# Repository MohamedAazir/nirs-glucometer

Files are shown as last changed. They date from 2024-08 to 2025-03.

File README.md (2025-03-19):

# Aprick by Meditrones
<p align="center">
Aprick
</p>
In our 2nd semester, for the module BM 1190 Engineering Design Project we came up  with an idea for building a Non - Invasive Bloodglucometer using NIR. So, this repository contains the whole work related to our project. The content includes, 

- [Problem Statement](#problem-statement)
- [Our Solution](#our-solution)
- [Technical Architecture](#technical-architecture)
- [PCB Design](#pcb-design)
- [Enclosure Design](#enclosure-design)
- [Problems Encountered and Solutions](#problems-encountered-and-solutions)

## Problem Statement
Diabetes is a chronic metabolic disorder that occurs when the body either does not produce enough insulin or cannot effectively use the insulin it produces. Without proper insulin function, glucose builds up in the bloodstream, leading to high blood sugar levels (hyperglycemia), which can cause serious health complications.
Diabetes management requires frequent blood glucose monitoring, typically done using **finger-prick glucometers**. However, this traditional method presents several challenges:  
- **Pain & Discomfort**: Repeated pricking can be painful, discouraging frequent monitoring.  
- **Risk of Infection**: Regular use of lancets increases the chance of **skin infections** and irritation.  
- **Disease Transmission**: Sharing glucometers without proper sanitization can spread **bloodborne diseases** such as Hepatitis and STDs.  
- **Needle Phobia**: Individuals with a fear of needles often avoid testing, leading to **poor glucose regulation**.  

These challenges highlight the **need for a non-invasive, pain-free, and user-friendly alternative** that ensures continuous glucose monitoring without compromising accuracy.  

## Our Solution  
As a solution for this issue We proposed a solution of developing a **NIR Based Non-Invasive Glucometer** that allows diabetes patients to check their glucose levels **without drawing blood**.  

### Key Features of the Device
- **Non Invasive**: No need of pricking again. The device functionality is totally non invasive and painless.
- **Real-time monitoring**: The device provides real-time values of the blood glucose levels.
- **User friendly**: Simple finger placement mechanism for hassle-free use. OLED display for clear and easy-to-read results.
- **Portable**: Compact, lightweight design for easy carrying.

## Technical Architecture
The technical perspective of our device comprises of **four main parts**:

### 1. Signal Transmission & Reception  
<p align="center">
  Description

</p>
The process begins when an near-infrared (NIR) beam is emitted by an IR LED with a wavelength of 940 nm. As the infrared light passes through the skin and tissue, it interacts with the biological components in the finger, primarily the blood. Specifically, the near-infrared light is absorbed by glucose molecules present in the blood. The absorption of light by these molecules causes a reduction in the intensity of the transmitted light. The remaining light is then detected by a photodetector, which is the CJ-MCU OPTO 101 module, which is sensitive to the intensity of the incoming light. This photodetector generates a corresponding voltage signal based on the amount of light it receives, which varies depending on the concentration of glucose in the blood. This voltage signal is then sent to the processing unit for further analysis. 

### 2️. Signal Processing & Analysis  

<p align="center">
  Description

</p>
The received signal first passes through a passive high-pass filter. The purpose of this filter is to eliminate any DC offset present in the signal, ensuring that only the variations in the signal, such as the fluctuations caused by glucose absorption, remain. This step is crucial because DC offsets can distort the signal, leading to inaccurate measurements.

Next, the signal is passed through a first-order active low-pass filter. This filter is designed to remove unwanted high-frequency noise that may be present in the signal. High-frequency noise, which can originate from various sources such as electrical interference or environmental factors, can obscure the desired signal and affect the accuracy of the measurement. The active filter helps to preserve the low-frequency components of the signal, which are more relevant for detecting glucose levels, while attenuating the higher-frequency noise.

After the signal has been filtered, it is then sent to an amplifier. The amplifier increases the amplitude of the signal, making it more suitable for further processing or analysis. This amplification ensures that the signal is strong enough to be accurately interpreted by subsequent stages of the system.

### 3️. Glucose Level Calculation & Display  
Finally, after the signal has been amplified and processed, it is sent to a pre-trained Linear Regression model. This model has been trained on a dataset that correlates voltage signals with known blood glucose levels, enabling it to make predictions based on the processed signal. The model applies the learned relationship between the voltage variations and glucose concentrations, using the input voltage signal to calculate the blood glucose level in real-time. Once the model processes the signal, the estimated blood glucose level is displayed on an OLED screen in milligrams per deciliter (mg/dL), which is the standard unit for measuring blood sugar levels.

### 4️. Power Supply System  
The device is powered by a 3.7V 500mAh LiPo battery, chosen for its lightweight and high energy density, ideal for portable use. A booster module increases the battery voltage to 12V. This 12V is then regulated down to 5V using a voltage regulator, which powers the microcontroller, amplifier, filters, and OLED display. The voltage regulation ensures stable operation and protects sensitive components from voltage fluctuations, allowing the device to run efficiently while optimizing battery life.  

## Firmware

The firmware for the microcontroller is written in C++ using the PlatformIO IDE. It handles the calculation of blood glucose values by applying the pre-trained Linear Regression model to the processed voltage signal. The firmware also manages displaying the glucose levels on the OLED screen in real-time and updates the display with the current value in mg/dL. Additionally, it indicates the status of the device, at which stage the process currently lies on.

<p align="center">
   Description
</p>

## PCB Design

To accomplish the tasks in our project, we designed two PCBs: the emitter LED PCB and the main PCB. The emitter PCB is a single-layer design, optimized for simplicity and functionality. The main PCB, on the other hand, is a more complex two-layer design, allowing for better routing and integration of components. Both PCBs were designed using Altium, a professional PCB design software, to ensure precision and reliability in the layout. Once the design was complete, the PCBs were printed and manufactured by JLCPCB, a trusted provider of high-quality PCB fabrication services.

<p align="center">
  Description

</p>

<p align="center">
  Description

</p>

## Enclosure Design
The enclosure of our device is inspired by the general structure of a pulse oximeter, ensuring a compact, ergonomic, and user-friendly design for comfortable handheld use. It consists of four main parts: the top lid, top compartment, bottom compartment, and bottom lid. These sections are carefully designed to securely house the internal components while providing ease of access for assembly and maintenance.

For increased accuracy, enhanced comfort and stability, we have used black TPU (Thermoplastic Polyurethane) material for the padding where the user inserts their finger. TPU is chosen for its flexibility, durability, and soft texture, ensuring a snug fit while minimizing discomfort during measurements. The rest of the enclosure is 3D-printed using PLA.
<p align="center">
  Description

</p>
<p align="center">
  Description

</p>

## Problems Encountered and Solutions

- **Noise in Circuit**: Resolved by utilizing active filters.
- **IR Receiver Issues**: Switched to the CJ-MCU OPTO 101 module hoping for better performance. But it didn't provide accurate results as expected.
- **Ethical Issues**: encountered an ethical issue of getting a large enough dataset to train the linear regression model.

## Our Team

- [@MohamedAazir](https://github.com/MohamedAazir)
- [@msboralugoda](https://github.com/msboralugoda)
- [@Banu-Liyanage](https://github.com/Banu-Liyanage)
- [@Madusanka20](https://github.com/Madusanka20)

</p>
<p align="center">
  Description

</p>

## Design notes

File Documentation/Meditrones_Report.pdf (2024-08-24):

# University of Moratuwa

## Faculty of Engineering

## Department of Electronic and Telecommunication Engineering


# NIR Based Non-Invasive Glucometer

## BM 1190: Engineering Design Project

## Group Members

Index Number Name

220005R | Aazir M.M.M.
220074B | Boralugoda M.S.
220362G | Liyanage D.L.B.B.
220374U | Madusanka S.P.S.

## Abstract

### Non invasive glucometer provides a prospective approach for patients

### with diabetes with the advantages of no pain and enabling continuous

### monitoring. A near infrared LED and photo detector is used to measure

### the blood concentration. The blood glucose level is calculated based on

### the scattering and absorption of infrared light through blood and then

### displayed on OLED.With our device we hope the patients can get an

### indication about the glucose level and take necessary actions. We believe

### the user friendliness of the device will meet the user needs of the target

### market as well as ensure the technical feasibility of the device to expected

levels of the market.

# Contents

1. Problem Description
(a) 1.1 Arriving at the Problem | 3
(b) 1.2 Arriving at a Solution | 3
(c) 1.3 Motivation | 3
(d) 1.4 Justification | 3
2. Feasibility
(a) 2.1 Technical Feasibility | 4
i. 2.1.1 Hardware Feasibility | 4
ii. 2.1.2 Software Feasibility | 5
(b) 2.2 Economic Feasibility | 5
3. Usage | 5
4. Product Architecture | 5
5. PCB Design | 7
6. Enclosure Design | 8
7. Final Product and User Guidance | 9
8. Problems Encountered and Solutions | 9
9. Marketing, Sales, and After-Sale Service Analysis | 10
10. Task Allocation | 10
11. Project Budget | 11

## Problem Description

### 1.1 Arriving at the Problem

There are several reasons not to use a traditional finger prick glucometer:

- Some diabetes patients require regular testing of blood glucose levels, and using the finger prick can be painful. This pain might create reluctance in them to take regular tests, which can be risky for some patients.
- Due to the needle used in finger pricks, it can cause skin infections and irritations with regular use of the same needle.
- If the same glucometer is used by several patients, there is a high risk of spreading blood-based diseases such as STD, Hepatitis, Malaria, etc.
- A certain group of people who fear needles and who are hemophobic might face several difficulties in using the traditional glucometer.

### 1.2 Arriving at a Solution

Non invasive glucometer provides a prospective approach for patients with diabetes with the advantages of no pain and enabling continuous monitoring. A near infrared LED and photo-detector is used to measure the blood concentration. The blood glucose level is calculated based on the scattering and absorption of infrared light through blood. 940nm was chosen as suitable wavelength as it optimizes the absorption by glucose molecules.

### 1.3 Motivation

The proposed device is capable to overcome the shortcomings in the traditional invasive methods to measure blood glucose levels and make it comfortable for the user.The user friendliness of the device makes it suitable for usage by any person and get an indication about their glucose levels anywhere at anytime.This device also leads the pathway for CGM(Continuous Glucose Monitoring) which can be vital for early detection of diabetes.

### 1.4 Justification

As per the survey conducted by our team Meditrones that included several groups of people who were suffering from diabetes or had close proximity to a diabetes patient revealed that the majority of them have access to a diabetes patient.

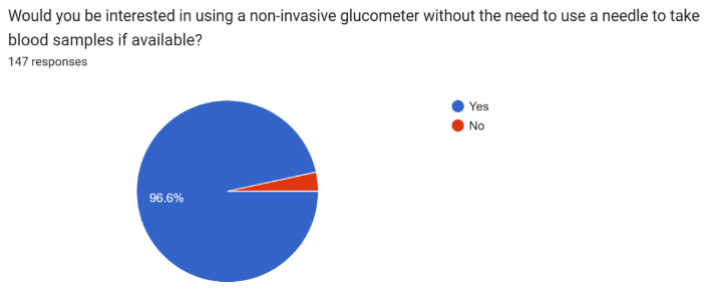
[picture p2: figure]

Figure 1: Survey Results

We believe that a non-invasive glucometer would be an ideal replacement for the finger prick glucometer and can be more user friendly for the patients but it requires to maintain a precise accuracy in the readings as well which could be a challenge in our project however with the deployment of proper technological methods we are eager to make it a reality so that we can make blood glucose monitoring more efficient and safe.

## 2. Feasibility

### 2.1 Technical Feasibility

All our resources were obtained easily from the local market thus it is technically feasible.Filter circuits and amplification processes were done from circuits built using passive and active elements. PCB was designed by us and the components were soldered by us to the PCB, the enclosure was also designed by us and got it printed using PLA+ white and black material using 3D printing.

### 2.1.1 Hardware Feasibility

All the required hardware components were available in the local market and we were able to implement the expected circuit from them. Following hardware components were mainly used in our project:

- Atmega 328P-AU
- SMD Resistors
- Ceramic and mylar Capacitors

- JST connectors and step up booster
- CJ-MCU OPTO 101 light reciever module
- Main PCB to connect other components

### 2.1.2 Software Feasibility

Software requirements for our micro controller are C++.The software utilizes algorithms to process sensor data, calibrate readings, and ensure accurate glucose level estimation without the need for invasive procedures.Overall, the software is feasible with a focus on accurate data processing, user-friendly interface, and reliable performance integration with the non-invasive sensor.

### 2.2 Economic Feasibility

The device aims to address the significant market need for non-invasive glucose monitoring. Potential benefits include reduced long-term healthcare costs due to improved diabetes management and patient compliance in comparison to the invasive methods that requires constant replacement of pricks which could be costly.The target pricing should be competitive yet reflective of the value provided by non-invasive monitoring, considering both production costs and market expectations.
Overall, the economic feasibility indicates that with strategic cost management and a clear market advantage, the non-invasive glucometer is a viable investment.

## 3. Usage

This device targets individuals that requires to get an indication about the blood glucose levels and get necessary actions for further medications. We expect this device to be used in households only to get a substantial idea about the current glucose level and to make sure early identification is done for patients with high risk without the need of invasive methods.

## 4. Product Architecture

The product architecture consists of the following sub-systems:

i. Signal Transmission and Receiving

We use a Receiver Module(CJ-MCU OPTO 101) to receive the IR beam emitted by an IR LED of wavelength 940nm implemented on the PCB and the output voltage of the module is fed into the next circuit for further analysis.

ii. Signal Analysis

The received voltage signal is sent through a low pass filter to cut off the power line interference and then through a high pass filter to make it a band pass signal within the centre frequency of the glucose resonant frequency, all the filter circuits are active filters making it more suitable for signals with high noise then the output of this circuit combination is fed into the MCU.

iii. Output

After proper analysis of the received signal to the MCU it compares the voltage value with the pre calibrated values and the corresponding calculated glucose value will be displayed on the OLED screen.

iv. Power supply

Power to the circuit is obtained using a 3.7V 500mAh Lipo battery and it is fed into a up convertor booster of 1.5A to obtain an output voltage of 12V which is then regulated to 5V using a voltage regulator and distributed along the PCB for the relevant connections.

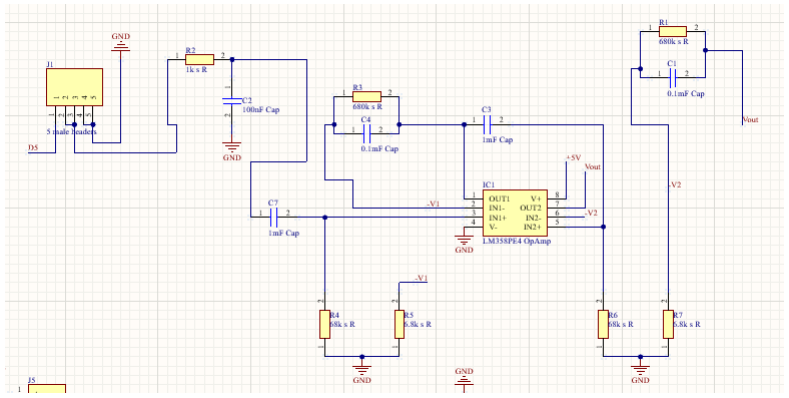
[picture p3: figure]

Figure 2: Filtering and Amplifying Circuit

## 5. PCB Design

The PCB Design of our device is shown below where we had one main PCB and another PCB for the transmitter:

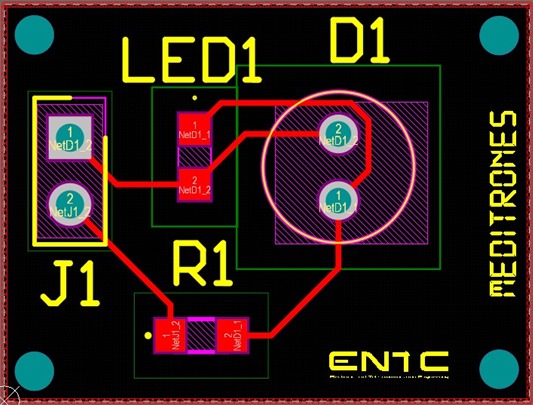
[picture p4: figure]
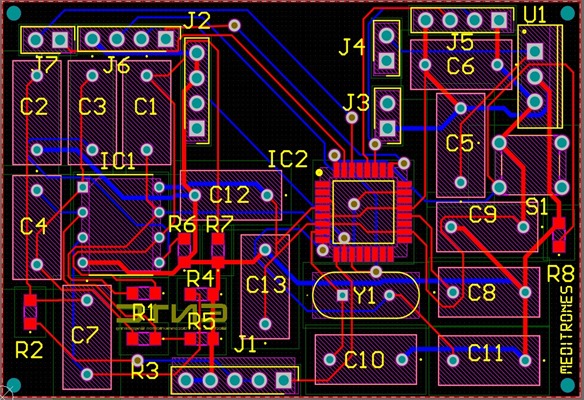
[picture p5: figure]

Figure 3: Main PCB | Figure 4: PCB for transmitter

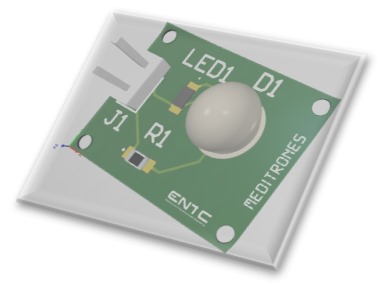
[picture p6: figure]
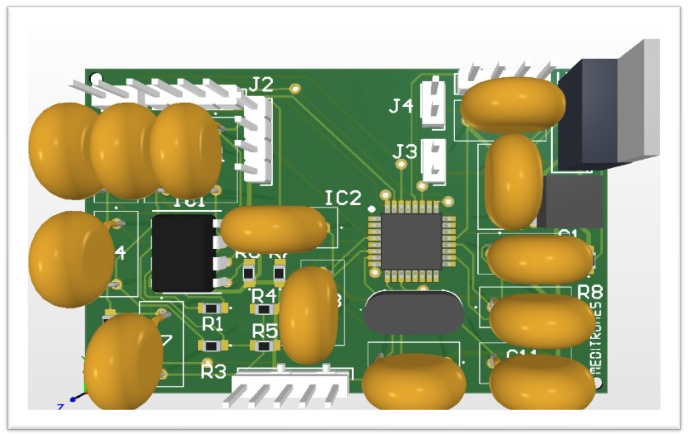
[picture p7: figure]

Figure 5: 3D view of Main PCB | Figure 6: 3D view of Transmitter PCB

## 6. Enclosure Design

The Enclosure was designed using solidworks and the sketches are shown below, we used PLA+ material to print our enclosure and Black TPU for the padding:

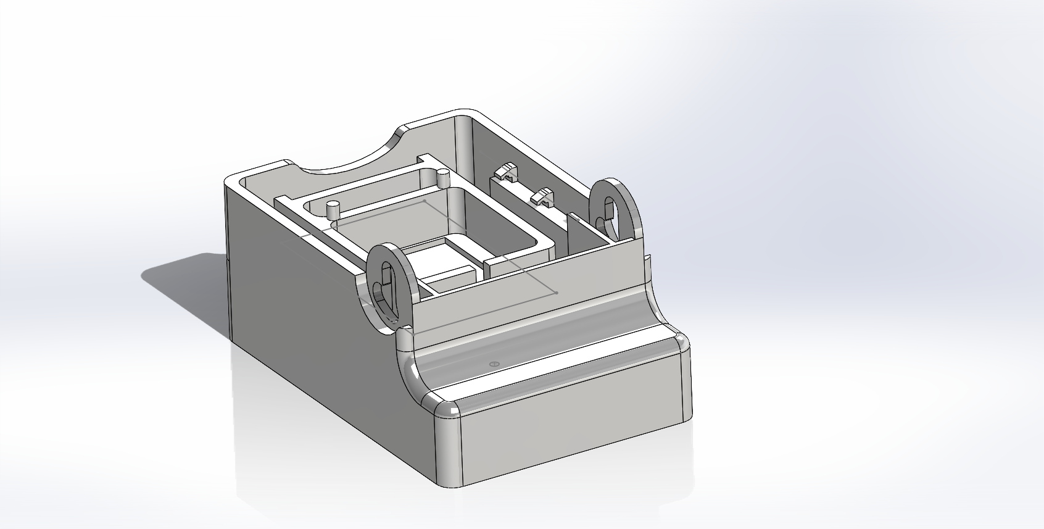
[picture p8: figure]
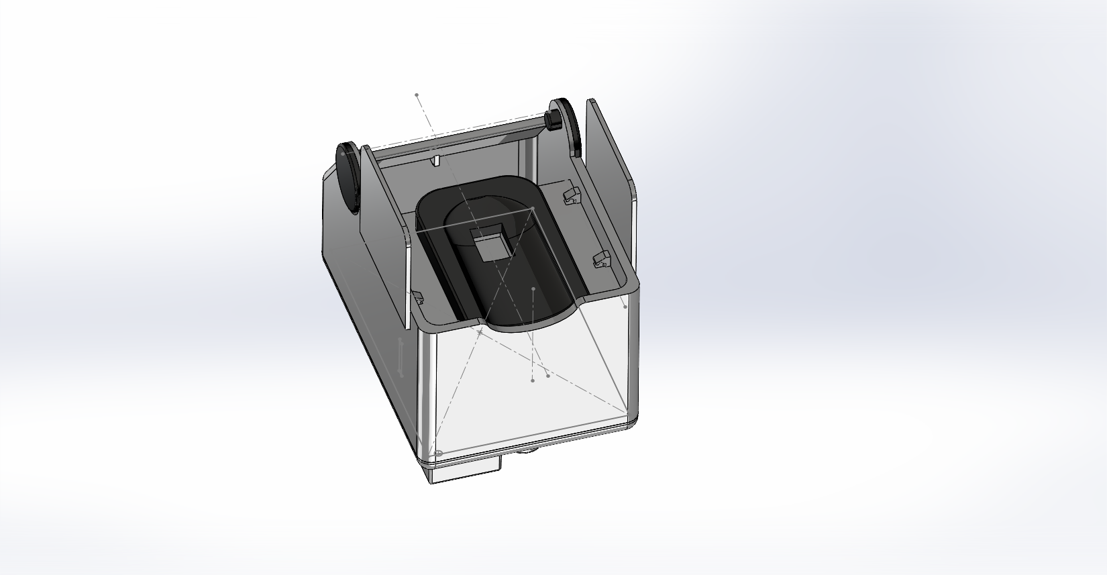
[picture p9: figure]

Figure 7: Bottom Compartment

Figure 8: With finger padding

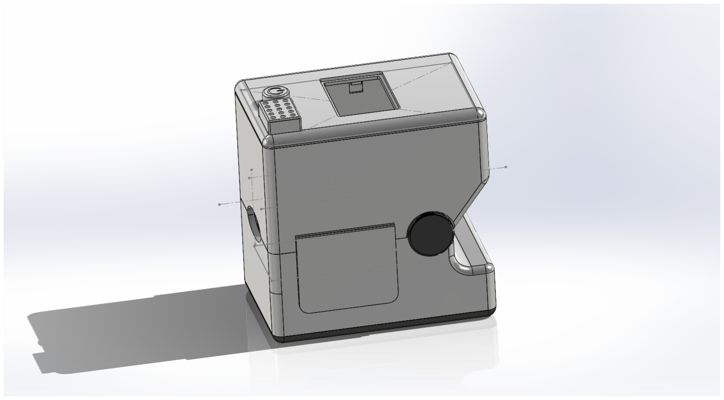
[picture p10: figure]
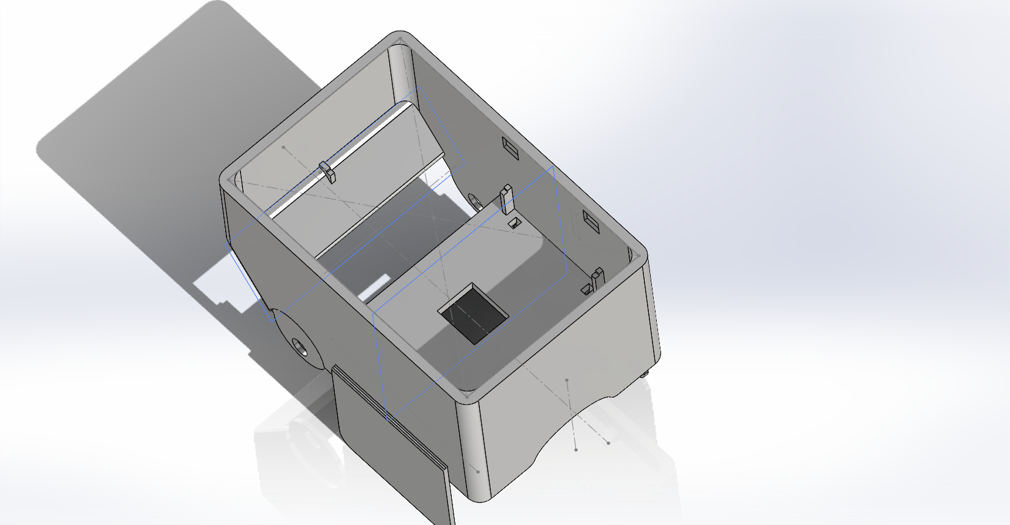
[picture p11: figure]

Figure 9: Combined Compartments | Figure 10: Top Compartment

## 7. Final Product and User Guidance

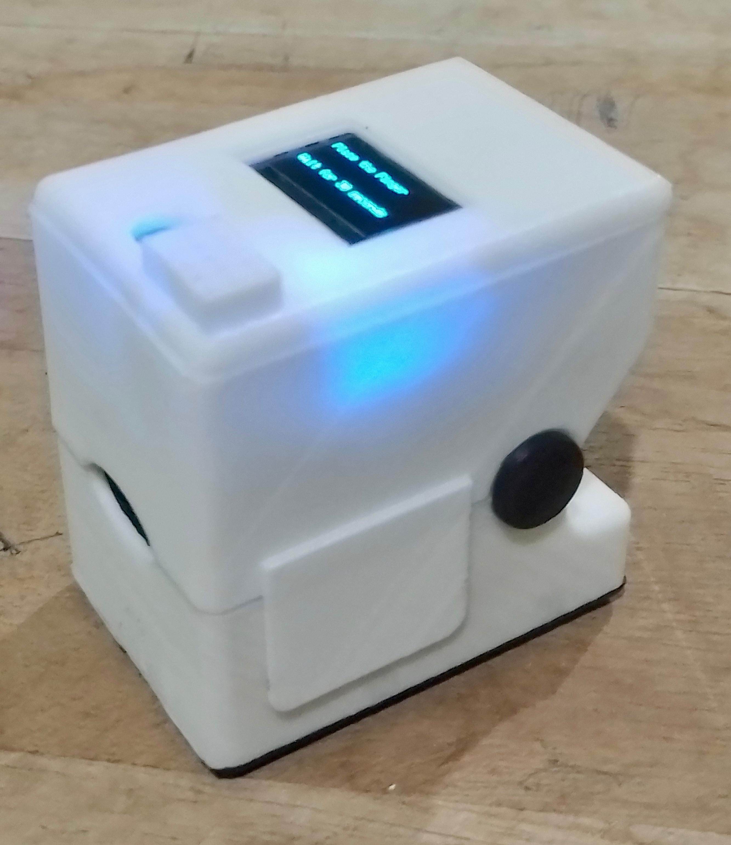
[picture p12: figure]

Figure 11: Final Assembled Device

Press the power button to turn on the device. Open the clamp and place your finger inside with the nail facing upwards. Ensure your finger is fully inserted, then release the clamp. Remain still while the device is measuring to get an accurate reading. The device will automatically start measuring your blood glucose level. Read the Results after 30 seconds, the results will display on the screen.The glucometer will automatically turn off after a few seconds of inactivity.

## 8. Problems Encountered and Solutions

1. Finalizing the circuit was a challenge at first due to extreme noise and filter deformations,as a solution we decided to utilize active filters and we got better results afterwards, furthermore to reduce the cost we used a dual Op-amp for the filters.
2. We were not able to obtain a reasonable output from the traditional IR receiver LED thus we decided to use a light receiving module (CJ MCU-OPTO 101) which gave us expected results.
3. Due to a technical faulty we were not able to program the atmega 328p-au chip but we used a TQFP-32 clamp shell and successfully uploaded the code afterwards.

## 9. Marketing, Sales, and After-Sale Service Analysis

Marketing Strategy

Our primary focus will be to educate the public on the non-invasive glucometer’s convenience and safety for household use. The device is designed to provide an indication of blood glucose levels, helping users monitor their health at home. However, it is essential to consult a healthcare professional for diagnosis and treatment decisions. Marketing efforts will include collaborations with local pharmacies, clinics, and online campaigns targeting individuals and families managing diabetes.

Sales Approach

The glucometer will be available for purchase at local pharmacies and through an online store, making it easily accessible to households across Sri Lanka. We will also work with healthcare providers to promote the device as a supplementary tool for at-home monitoring.

After-Sale Service

We are committed to supporting our customers with after-sale services that include guidance on proper use, customer support , and routine updates. It’s important to note that while the glucometer is useful for regular monitoring, it should not replace professional medical advice. Always consult a doctor for accurate diagnosis and treatment.

## 10. Task Allocation

- Research: Aazir, Manuri, Banuka
- Circuit Development: Aazir, Banuka, Sahan
- PCB Design: Sahan
- Enclosure Design: Aazir, Manuri
- Circuit Implementation: Banuka, Sahan
- Code: Aazir, Banuka
- Documentation: Manuri, Banuka

## 11. Project Budget

Component | Unit Price | Quantity | Price(Rs.)
Passive Elements | | | 100
Dual Op-Amp | 30 | 1 | 30
OLED Display | 450 | 1 | 450
PCB | | | 350
3D Printing | | | 2500
Receiver Module (CJ MCU-OPTO 101) | 2000 | 1 | 2000
JST Connectors | 20 | 3 | 60
Lipo Battery | 200 | 1 | 200
Booster Module | 150 | 1 | 150
5V Regulator | 50 | 1 | 50
Atmega 328P-AU Chip | 1500 | 1 | 1500
Push Button | 10 | 1 | 10
Total | | | Rs.7400

Table 1: Project Budget

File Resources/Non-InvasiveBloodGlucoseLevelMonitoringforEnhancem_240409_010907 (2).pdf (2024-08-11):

Non-Invasive Blood Glucose Level Monitoring for Enhancement using ML (https://www.researchgate.net/publication/360289594_Non-Invasive_Blood_Glucose_Level_Monitoring_for_Enhancement_using_ML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)

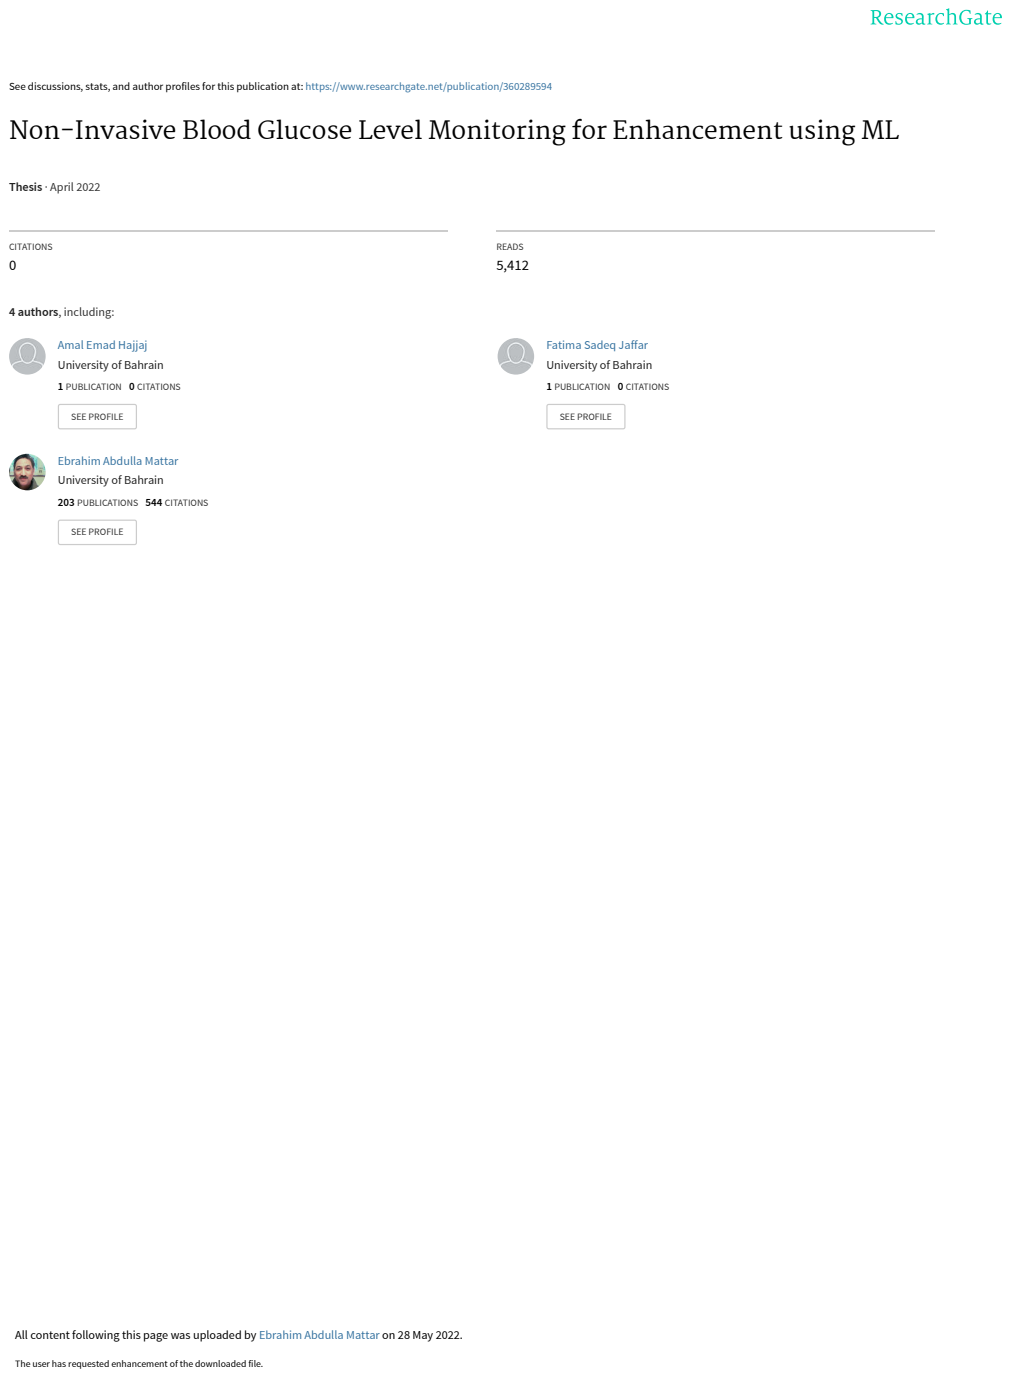
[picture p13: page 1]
Thesis · April 2022; CITATIONS 0; READS 5,412; 4 authors, including:; 1 PUBLICATION 0 CITATIONS; SEE PROFILE; 203 PUBLICATIONS 544 CITATIONS

See discussions, stats, and author profiles for this publication at: https://www.researchgate.net/publication/360289594

Amal Emad Hajjaj (https://www.researchgate.net/profile/Amal-Hajjaj-3?el=1_x_5&_esc=publicationCoverPdf)
University of Bahrain (https://www.researchgate.net/institution/University_of_Bahrain?el=1_x_6&_esc=publicationCoverPdf)

Fatima Sadeq Jaffar (https://www.researchgate.net/profile/Fatima-Jaffar-3?el=1_x_5&_esc=publicationCoverPdf)

Ebrahim Abdulla Mattar (https://www.researchgate.net/profile/Ebrahim-Mattar?el=1_x_5&_esc=publicationCoverPdf)

All content following this page was uploaded by Ebrahim Abdulla Mattar (https://www.researchgate.net/profile/Ebrahim-Mattar?el=1_x_10&_esc=publicationCoverPdf) on 28 May 2022.

The user has requested enhancement of the downloaded file.

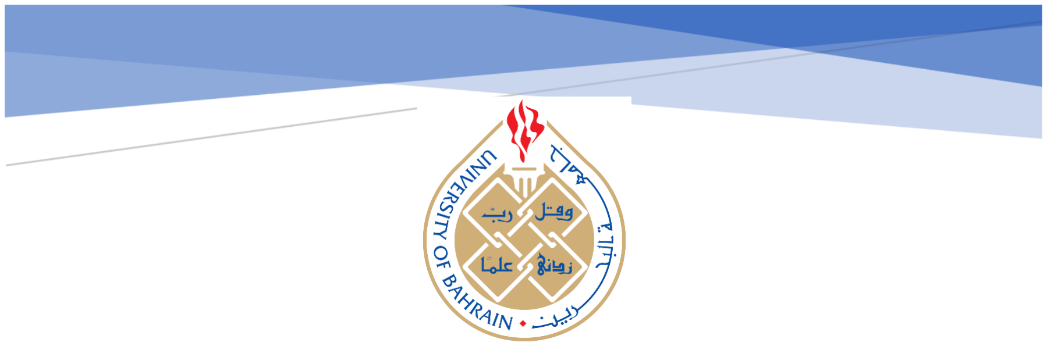
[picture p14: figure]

I

# Non-Invasive Blood Glucose

# Level Monitoring for Enhancement using ML

A Senior Design Project (EENG490) Report

Submitted in partial fulfillment of the requirements for the degree of B.Sc. in Electrical (or Electronics) Engineering

## Bahrain University

## College of Engineering

## Electrical and Electronics Engineering Department

Student Name (s) and ID:

1. Amal Emad Hajjaj 20184362
2. Fatima Sadeq Kadhem 20187159
3. Rawan Waleed Alakool 20185038

Supervisor: PROF. EBRAHIM ABDULLA MATTAR

Starting Date: 11st Feb 2022

II

# ACKNOWLEDGMENT

I would like to express our thanks and appreciation my supervisor Prof. Ebrahim

Abdullah Mattar for his continuous support and advice. Special thanks to all the helping

colleagues that helped us in understanding some of the project parts (Amnah Mohammad and

Sajjad Aljaziri), also we want to thank Mr. Mohammad (the lab technician) at the Department

stores; he has provided the parts to make our project real.

III

# STATEMENT OF AUTHENTICITY

By submitting this senior project report, we declare that:

i. We are aware and fully understand the Plagiarism Policy of the University of

Bahrain.

ii. | We have not knowingly violated any ethical codes of conduct and our work has
| taken all ethical issues into consideration.
iii. | We confirm that the research that was developed during the senior project course
| has been original work that adheres to the Plagiarism Policy of the University of
| Bahrain and has not been submitted for any other course.
iv. | We have quoted and paraphrased work done by other authors. These were
| acknowledged in the text and properly referenced in the references section.
v. We are aware and fully understand that we will be referred for investigation for
| academic misconduct, have we submitted any work which is not our own.
Students Name: | Student Signature:
1. Amal Emad | Amal
2. Fatima Sadeq | Fatima
3. Rawan Waleed | Rawan

IV

# ABSTRACT

Diabetes is a common chronic disease in mostly all countries worldwide. The most used

method to measure glucose level in blood is an invasive method which is painful, expensive

and danger in spreading infectious diseases. Over a long term, the invasive method results in

damage of finger tissues. As an alternative, the non-invasive method can be used which

facilitates frequent testing, relieves pain and discomfort caused by frequent finger pricks. A

non-invasive method of glucose level measurement is proposed in this paper. The variation in

the intensity of NIR light received from the photo detector after passing through the finger is

used to determine the glucose level of blood. The measured glucose level is displayed in LCD

display and transmitted to the android application which is created in the mobile phone to

display and store data via Bluetooth.

V

# CONTENTS

VI

VII

APPENDIX 41

VIII

# LIST OF FIGURES

IX

# LIST OF TABLES

X

# ACRONYMS

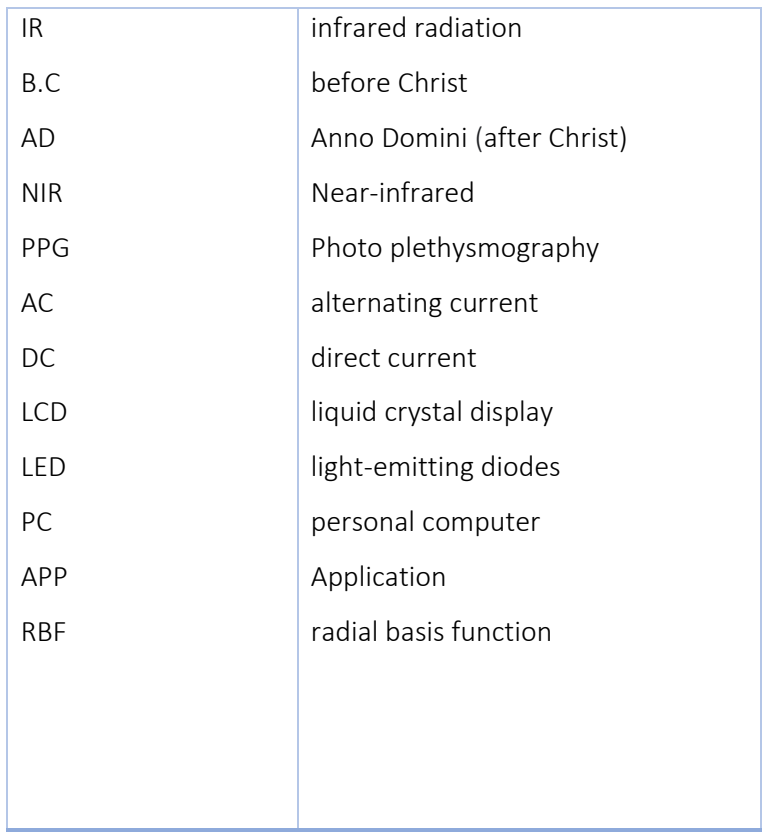
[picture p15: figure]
NIR; PPG; LCD; LED; APP; RBF; infrared radiation; before Christ; Anno Domini (after Christ); Near-infrared; Photo plethysmography; alternating current; direct current; liquid crystal display; light-emitting diodes; personal computer; Application; radial basis function

XI

# LIST OF SYMBOLS

μa

I

Mg/dl

absorption coefficient

effective optical path length

Milligrams per deciliter

# CHAPTER 1

# INTRODUCTION

Diabetes is a type a metabolic Diseases in which the blood glucose (blood sugar) level in

human body increases drastically from its normal level. The increase in sugar level is either

due to inadequate production of insulin in blood cells or can be because of improper

response of body cells to the insulin or can be because of both the reasons. diabetes can lead

to major complications like heart failure and blindness in the human body. Hence regular

monitoring of glucose level is important. There are more than 200million people with

diabetes . Diabetes is a state of a body where it is not able to produce the quantity of insulin

sufficiently required to maintain normal level of blood glucose. So, diabetic patients reg up

their blood glucose levels through proper diet as well as by injecting insulin. For the effective

treatment of diabetes, patients have to measure the level of blood glucose periodically3-5. At

present, diabetic persons are using invasive figure breaking instrument knows as glucose

meter to know the concentration of blood glucose. In pathology laboratories, glucose is

measured by piercing a patient's finger with a lancing needle. Take a small amount of blood

sample. Then a blood sample is placed on the strip and inserted in a blood glucose meter.

Development of a non-invasive glucose measurement technique would be a boom for a

diabetic patient. The major advantage of noninvasive measurement methods is the relief

from pain and comfort due to no finger puncturing. The method for glucose measurement

like IR spectroscopy is popular from years, but method with a reliable result has not been

established yet [1].

Figure 1. No for the invasive method of measuring blood sugar, [22].

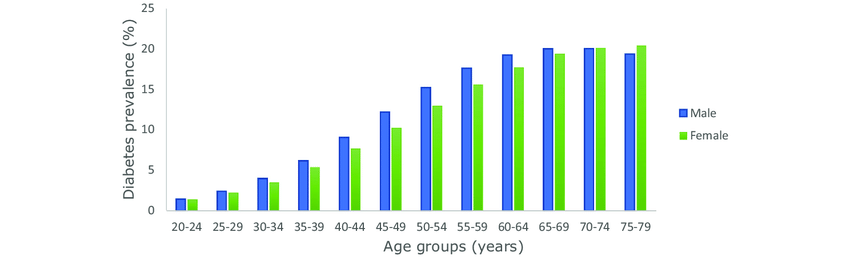
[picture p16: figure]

### 1.1 Motivation

“Health organization shows that the amount of people that got diabetes disease in 1980 is

108 million and became 422 million in 2014. Prevalence has been rising more rapidly in low-

and middle-income countries than in high-income countries. In Between 2000 and 2016,

there was a 5% increase in premature mortality from diabetes. In 2019, diabetes was the

ninth leading cause of death with an estimated 1.5 million deaths directly caused by

diabetes”. After we saw the numbers and the amount of people that suffers from needles and

injections, we wanted to help them in having an easy life without the pain of the injunctions

whenever they want to measure their blood glucose.

## 1.2 Aim of the project

The way that this project works is that we used an IR sensor with a special wavelength that

can penetrate the skin of the finger, this IR wave will go through the finger and collide with

the blood cells which cause a reflection, after the reflection of the wavelength the receiver

will receive this wave, then the Arduino will process the wave and find the glucose level of

the, what proves that the project works perfectly if the percentage error between the

invasive method and the noninvasive is a very small percentage.

Figure 2: Diabetes prevalence by age and sex in 2019, [18]

## 1.3 Constraints

The project includes many constraints that must be taken into account to ensure the

success of the project:

i. To obtain guaranteed results, the sensor must be placed on a solid and stable

surface such as a table or wood, and when placing the finger on the sensor, it must

be pressed firmly and firmly, and it must also be pressed for 10-15 seconds to

obtain a stable result.

ii. The environment of the experiment, the light and the temperature had an effect

on the results, so we tried to work under constant conditions, we also tried to

count in one place at a constant temperature and we tried to fix the finger well on

the sensor to prevent the light from entering

iii. Design, where the Arduino has a specified amount of current and voltage. One of

its Constraints is that the current works with the voltage in reverse, as when the

device takes a very large current, this leads to a significant decrease in the voltage

in the supply of the Arduino .

iv. Cost and weight, it should have an appropriate cost so that people can buy it and it

should contain lightweight components in order to be easy to carry and use .

## 1.4 Standards:

i. Arduino UNO Standards.

ii. IEEE 802.11 (Bluetooth ISM 2.4 GHz).

iii. For report departments SP standard template.

iv. 16x2 LCD Module

v. USB 3.0 and USB 2.0.

vi. TCRT5000 IR Sensor

## 1.5 Report Outline

In this report, we will talk about measuring blood sugar by a non-invasive method. In the

second chapter, we will talk about biological aspect We started by talking about diabetes and

its history, then we talked about glucose, then the layers of the human skin, then we got

acquainted with the rays that penetrate the finger and interact with glucose molecules, and

at the end of this section we learned about the method of measuring blood sugar in a non-

invasive way. In chapter3 we put our initial work, part aspect, codes and Block diagram of

proposed work. In chapter4 we put our final device, our results and error methods. In

chapter5 we talked about the discussion and in chapter6 it will be about the conclusion. At

the end of the report, we talked about Literature.

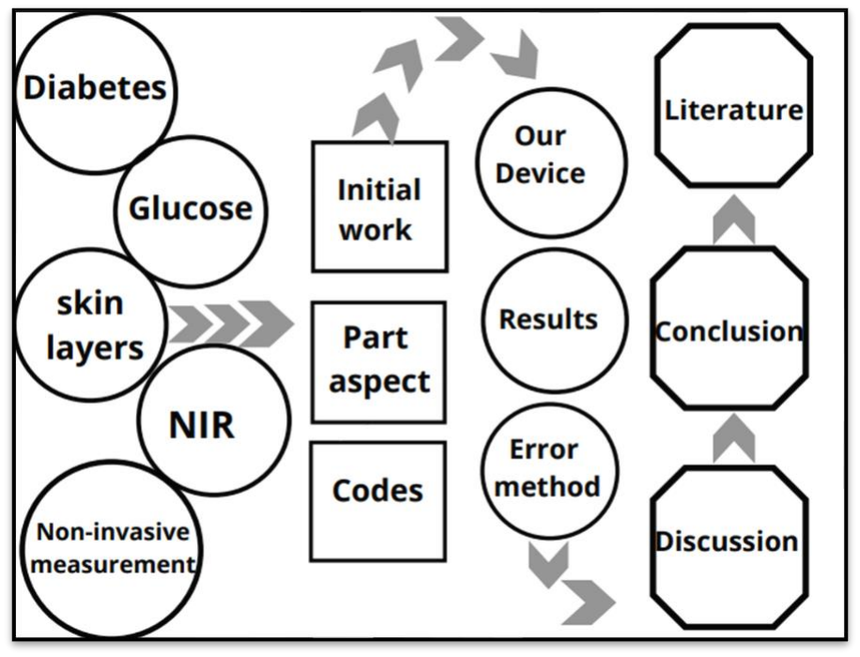
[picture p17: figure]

Figure 3: The report outline

# CHAPTER 2 BLOOD GLUCOSE BACKGROUND

## Biological Aspect

## 1.6 Diabetes history:

“Scientists and physicians have been documenting the condition now known as diabetes for

thousands of years. From the origins of its discovery to the dramatic breakthroughs in its

treatment, many brilliant minds have played a part in the fascinating history of diabetes”.

## The Literature

In this section, a literature review on measuring blood glucose using NIR spectroscopy and

measuring bilirubin using optical method has been presented. Müller et al. in 1997 used NIR

diffuse reflectance spectra method in the range of 800–1350 nm to measure glucose from

finger. The cross-validation root means square error of prediction (RMSEP) obtained is from

1.02 mmol/L (18.4 mg/dL) to 1.88 mmol/L (33.8 mg/dL). Danzer et al. in 1998 used NIR diffuse

reflectance with partial least squares (PLS) regression and analysis of radial basis function

(RBF) neural network. They used 800–1350 nm NIR light and measured glucose from the

middle finger. The RMSEP obtained is 2.0 mmol/L (36 mg/dL). Araujo-Andrade et al. in 2004

used NIR diffuse reflectance method which consisted of a light source, a fiber optical

measuring head, and an NIR spectrometer. The NIR light with a wavelength of 900–1700 nm

was used, and the measurement is carried out from the finger. In this study, the correlation

coefficient values obtained are lower than 0.744 and RMSEP values obtained are higher than

0.89 mmol/L (16 mg/dL). Xu et al. in 2005 reported an optical measurement condition

reproduction technique to deal with the difference in measuring locations and contact

pressures. Their proposed system consists of light-emitting diodes (LEDs) for lighting, fibre

probe, spectrometer, CCD camera, three-dimensional servo device, and a brocket. They used

NIR diffuse reflectance spectra in the range of 1100–1800 nm to measure glucose from palm.

The obtained RMSEP ranges from 0.8 to 1.1 mmol/L (15–20 mg/dL), and the correlation

coefficient is greater than 0.8. Guevara and González in 2010 jointed NIR (700–1000 nm) and

impedance spectroscopy (1–200 MHz). They measured glucose from the forearm and tested

technique on 10 nondiabetic individuals under controlled temperature and humidity

conditions. The RMSEP obtained was 1.2488 mmol/L (21.96 mg/dL). Srivastava et al. in 2013

proposed an optical non-invasive method to measure the blood glucose by a 940-nm infrared

light emitted as the input signal on the finger.

The output signal could be digitized, amplified, and processed in a microchip with a special

algorithm designed to detect blood glucose levels. However, the proposed method has not

been evaluated. This paper concludes that non-invasive blood glucose measurements soon

can be a good alternative to market glucometers. In 2018 three Drs made a device that

measure glucose and bilirubin, Dr. Faranak Fotouhi-Ghazvini and Fahime Sadat Zakeri. They

used for their project (microcontroller, photodiodes transmitters, resisters, capacitors, LCD,

Bluetooth module). For the microcontroller they used C++ language, they took some blood

samples and compared it with their device samples and determined an equation. Their device

was approved by the Clarkes grid analysis and the percentage was between 3% to 12%.

The second one was made with using temperature, they took 50 human samples by using

LCD, Arduino, temp sensing, and amplification, there error rate was also approved from

Clarke’s grid analysis. So, after reading more than one article we decided to use Arduino

because it has more potentials and easier in using it, we also used in our sensor two stages of

amplification stages and one low pass filter with photodiodes and transmitter, also we will use

LCD and Bluetooth module to design an application that the Arduino will send the result

through connecting the Bluetooth module to the phone application.

1.6.1 Diabetes Beginnings
“The first known mention of diabetes symptoms was in 1552 B.C., when Hesy-Ra, an Egyptian

physician, documented frequent urination as a symptom of a mysterious disease that also

caused emaciation, also around this time, ancient healers noted that ants seemed to be

attracted to the urine of people who had this disease. In 150 AD, the Greek physician Arateus

described what we now call diabetes as "the melting down of flesh and limbs into urine."

From then on, physicians began to gain a better understanding about diabetes. Centuries

later, people known as "water tasters" diagnosed diabetes by tasting the urine of people

suspected to have it. If urine tasted sweet, diabetes was diagnosed. To acknowledge this

feature, in 1675 the word "mellitus," meaning honey, was added to the name "diabetes,"

meaning siphon. It wasn't until the 1800s that scientists developed chemical tests to detect

the presence of sugar in the urine” [2].

1.6.2 The Early Treatments for the disease
“As physicians learned more about diabetes, they began to understand how it could be

managed. The first diabetes treatment involved prescribed exercise, often horseback riding,

which was thought to relieve excessive urination. In the 1700s and 1800s, physicians began to

realize that dietary changes could help manage diabetes, and they advised their patients to

do things like eat only the fat and meat of animals or consume large amounts of sugar. During

the Franco-Prussian War of the early 1870s,

the French physician Apollinaire Bouchard at noted that his diabetic patients' symptoms

improved due to war-related food rationing, and he developed individualized diets as

diabetes treatments. This led to the fad diets of the early 1900s, which included the "oat-

cure," "potato therapy," and the "starvation diet."

In 1916, Boston scientist Elliott Joslin established himself as one of the world's leading

diabetes experts by creating the textbook The Treatment of Diabetes Mellitus, which

reported that a fasting diet combined with regular exercise could significantly reduce the risk

of death in diabetes patients. Today, doctors and diabetes educators still use these principles

when teaching their patients about lifestyle changes for the management of diabetes” [2].

1.6.3 How Insulin Came About

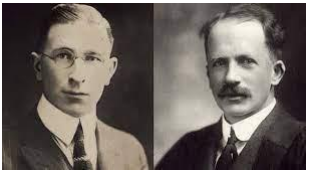
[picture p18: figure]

“Despite these advances, before the discovery of insulin, diabetes inevitably led to premature

death. The first big breakthrough that eventually led to the use of insulin to treat diabetes

was in 1889, when Oskar Makowski and Joseph von Mering, researchers at the University of

Strasbourg in France, showed that the removal of a dog's pancreas could induce diabetes. In

the early 1900s, Georg Zuelzer, a German scientist, found that injecting pancreatic extract

into patients could help control diabetes. Frederick Banting, a physician in Ontario, Canada,

first had the idea to use insulin to treat diabetes in 1920, and he and his colleagues began

trying out his theory in animal experiments. Banting and his team finally used insulin to

successfully treat a diabetic patient in 1922 and were awarded the Nobel Prize in Medicine

the following year” [2].

## 1.7 Diabetes Mellitus

Commonly known as diabetes, is a group of metabolic disorders characterized by a high blood

sugar level over a prolonged period. Symptoms often include frequent urination, increased

thirst and increased appetite, if left untreated, diabetes can cause many health complications,

Serious long-term complications include cardiovascular disease, stroke, chronic kidney

disease, foot ulcers, damage to the nerves, damage to the eyes and cognitive impairment

Figure 4: The discoverers of insulin, George Zelzer and Frederick Banting, [19].

Diabetes is due to either the pancreas not producing enough insulin, or the cells of the body

not responding properly to the insulin produced. There are three main types of diabetes

mellitus:

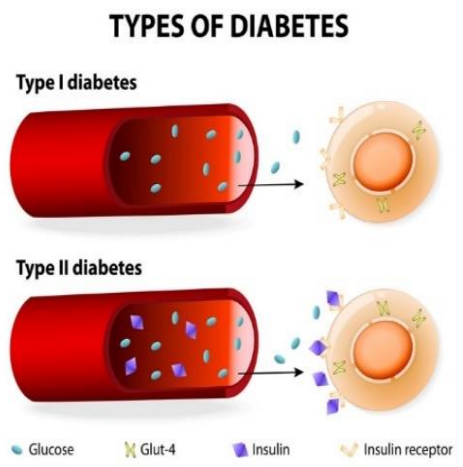
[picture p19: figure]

- Type 1 diabetes results from failure of the pancreas to produce enough insulin due to

loss of beta cells. The loss of beta cells is caused by an autoimmune response.

- Type 2 diabetes begins with insulin resistance, a condition in which cells fail to respond

to insulin properly, As the disease progresses, a lack of insulin may also develop, the

most common cause is a combination of excessive body weight and insufficient

exercise.

- Gestational diabetes, and occurs when pregnant women without a previous history of

diabetes develop high blood sugar level [4].

1.8 Glucose
Blood glucose is a sugar that the bloodstream carries to all cells in the body to supply energy.

A person needs to keep blood sugar levels within a safe range to reduce the risk of diabetes

and heart disease [5].

Figure 5: Types of diabetes mellitus [20].

What Is Glucose?
Glucose is a sugar that circulates the blood, serving as the body’s main source of energy.

When a person takes in carbohydrates, the digestive system processes them into sugar

molecules of different complexities. Complex carbohydrates, such as the lactose common in

dairy products, are harder for the body to break down. They contain different types of sugar

molecule. glucose is another product of carbohydrate breakdown. It is a simple sugar that

cells in the body can easily convert to energy. The sugar goes straight from the digestive

system into the bloodstream after an individual consumes and digests food.

However, glucose can only enter cells if enough insulin is also circulating in the bloodstream.

Insulin is a protein that makes cells ready to receive glucose. After people eat, blood sugar

concentrations increase. The pancreas releases insulin automatically to move glucose from

the blood to the cells. as more and more cells receive glucose, blood sugar levels return to

normal [5].

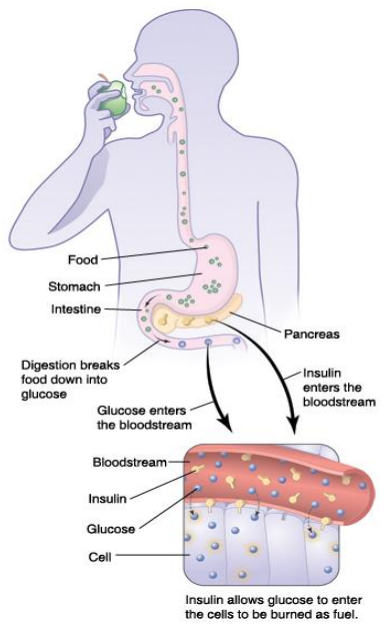
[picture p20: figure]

How The Body Makes Glucose
It mainly comes from foods rich in carbohydrates, like bread, potatoes, and fruit. As you eat,

food travels down your esophagus (https://www.webmd.com/digestive-disorders/picture-of-the-esophagus) to your stomach. (https://www.webmd.com/digestive-disorders/picture-of-the-stomach) There, acids and enzymes break it down

into tiny pieces. During that process, glucose is released. It goes into your intestines (https://www.webmd.com/digestive-disorders/picture-of-the-intestines) where it's

absorbed. From there, it passes into your bloodstream. Once in the blood, insulin helps

glucose get to your cells [6].

Figure 6: How the Body Makes Glucose, [21]

Energy and Storage
Our body is designed to keep the level of glucose in your blood constant. Beta cells in your

pancreas monitor your blood sugar level every few seconds. When your blood glucose rises

after you eat, the beta cells release insulin into your bloodstream. Insulin acts like a key,

unlocking muscle, fat, and liver cells so glucose can get inside them. Most of the cells in your

body use glucose along with amino acids (the building blocks of protein) and fats for energy.

But it's the main source of fuel for your brain. Nerve cells and chemical messengers there

need it to help them process information. Without it, your brain wouldn't be able to work

well. after your body has used the energy it needs, the leftover glucose is stored in little

bundles called glycogen in the liver and muscles. Your body can store enough to fuel you for

about a day. after you haven't eaten for a few hours, your blood glucose level drops. Your

pancreas stops churning out insulin. Alpha cells in the pancreas begin to produce a different

hormone called glucagon. It signals the liver to break down stored glycogen and turn it back

into glucose. That travels to your bloodstream to replenish your supply until you're able to eat

again. Your liver can also make its own glucose using a combination of waste products, amino

acids, and fat [6].

1.8.1 Blood Glucose Levels
blood sugar level normally rises after you eat. Then it dips a few hours later as insulin moves

glucose into your cells. Between meals, your blood sugar should be less than 100 milligrams

per deciliter (mg/dl). This is called your fasting blood sugar level.

Without enough insulin, glucose can't move into the cells. The blood glucose level stays high.

A level over 200 mg/dl 2 hours after a meal or over 125 mg/dl fasting is high blood glucose,

called hyperglycemia.

Too much glucose in your bloodstream for a long period of time can damage the vessels that

carry oxygen-rich blood to your organs. High blood sugar can increase your risk for:

a. Heart disease, heart attack, (https://www.webmd.com/heart-disease/guide/heart-disease-heart-attacks) and stroke
b. Kidney disease (https://www.webmd.com/a-to-z-guides/understanding-kidney-disease-basic-information)
c. Nerve damage (https://www.webmd.com/brain/nerve-pain-and-nerve-damage-symptoms-and-causes)
d. Eye (https://www.webmd.com/eye-health/ss/slideshow-eye-conditions-overview) disease called retinopathy [6].

## 1.9 Lifestyle tips

Lifestyle choices can often help to control blood sugar.

Eating a healthy diet with plenty of fruit and vegetables, maintaining a healthy weight, and

getting at least 150 minutes of moderate-to-intense exercise each week can help Trusted

Source. (https://www.ncbi.nlm.nih.gov/pubmed/30418471) Other tips for controlling blood sugar include:

i. eating at regular times and not skipping meals

ii. drinking water instead of juice and soda

iii. choosing fruit instead of a candy bar

iv. using portion control, so that a typical plate will be one-fourth meat, one-fourth

starchy foods, and one-half non-starchy vegetables

Any person who experiences symptoms of low or high blood sugar should see a doctor,

whether or not they have a diagnosis of diabetes [5].

## 1.10About Skin layers

The skin is the largest organ of the body, with a total area of about 20 square feet. The skin

protects us from microbes and the elements, helps regulate body temperature, and permits

the sensations of touch, heat, and cold. Skin has three layers:

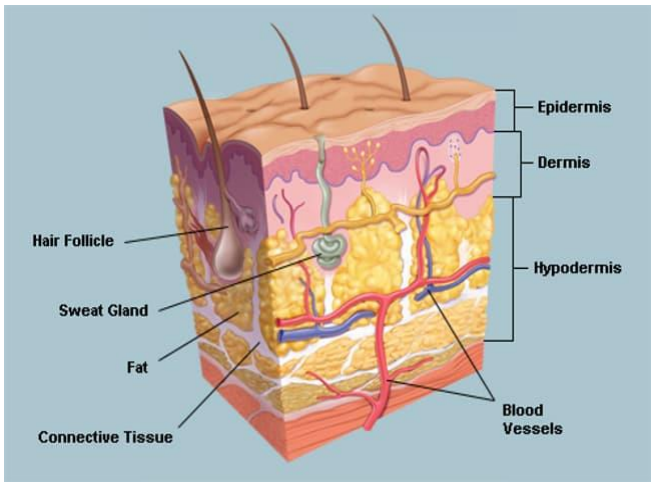
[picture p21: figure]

i. “The epidermis, the outermost layer of skin, provides a waterproof barrier and creates

our skin tone”.

ii. “The dermis, beneath the epidermis, contains tough connective tissue, hair follicles,

and sweat glands”.

iii. “The deeper subcutaneous tissue (hypodermis) is made of fat and connective tissue”.

The skin’s color is created by special cells called melanocytes, which produce the pigment

melanin. Melanocytes are in the epidermis [3].

Figure 7: The skin structure and layers, [5].

## 1.11NIR

Near-infrared spectroscopy (NIRS) is a spectroscopic method that uses the near-infrared region of the

electromagnetic spectrum (from 780 nm to 2500 nm). Typical applications include medical and

physiological diagnostics and research including blood sugar, pulse oximetry, functional neuroimaging,

there are also many applications use it.

1.11.1Range of Wavelengths

Glucose is a kind of monosaccharide with the molecular formula C6H12O6 in the form of pyranose. It has

several absorption peaks in the NIR region. where light possesses its maximum penetration depth in tissue

is referred as Near Infrared window. Glucose has light absorption peaks at wavelengths of 940 nm, 970

nm, 1197 nm, 1408nm, 1536nm, 1688nm, 1925 nm, 2100nm, 2261nm and 2326nm, but at 940 nm

wavelength the attenuation of optical signals by other constituents of the blood like water, platelets, red

Figure 8: Light skin penetration with different wavelengths (nm).

blood cells etc. is minimum, hence a desired depth of penetration can be achieved, and actual glucose

concentration can be predicted, [1].

## 1.12Non- invasive measurement:

1.12.1Measuring the level of glucose in the blood
Diagnosing systems for blood sugar system are invasive in nature. This procedure is performed by drawing

blood through puncturing the skin with a needle and applying it to a chemically active test strip. Another

procedure for diagnosing blood sugar is non-invasive method. Some of the existing non-invasive methods

are near infrared (NIR) detection, ultrasound and dielectric spectroscopy which do not need any supply

of blood for conducting the tests and calculating its result [7].

1.12.2Photo plethysmography
The skin tissue consists of three layers of which only dermis layer consists of information about blood

glucose. infra-red wavelength (780nm to 2500nm) is able to penetrate until the dermis layer, The

transmitted IR light will be absorbed by different skin tissues, different molecules in the blood like melanin,

keratin, fats, proteins, hormones etc. and the skin pigments. Variations in the volume of blood flow are

detected by the (PPG) sensors optically. It records the changes in reflected light intensity from the dermis

layer of skin. The light waveform consists of both direct Current (DC) and alternating current (AC)

components. The DC component of the PPG waveform corresponds to the optical signal is transmitted or

reflected from the tissues during changes in blood volume in this work, reflection photography It is

considered to non-invasively determine glucose levels. Here the light passes through the epidermal layer

and upon arrival, The light of the dermis is absorbed, scattered, and reflected by glucose molecules. The

intensity of light reflected from the dermis layer was examined to predict glucose levels [7].

1.12.3Principle of Blood Glucose Measurement
When a light ray interacts with human body tissues, it is attenuated by scattering as well as by absorption

by the tissues. Due to the mismatch between the refraction index of extracellular fluid and the cell

membrane, light scattering occurs in tissues. Refraction index of extracellular fluid varies with the glucose

concentration whereas the cellular membrane index is assumed to be remain relatively constant. Beer-

Lambert Law plays a major role in absorbance measurement which states that absorbance of light through any solution is in proportion with the concentration of the solution and the length path travelled by light

ray.

more glucose tissue results in less scattering, less optical path length and thus more absorption than

before tissues. Due to increased uptake in elevated glucose tissues Reflected light is less intense compared

to tissue with lower glucose content [1].

The attenuated light simply due to the absorption of analysts after they pass through tissue is governed

by the Beer–Lambert Law, which is expressed as:

## i = i0e

−iμai

Figure 9: Less glucose tissue, [1].

Figure 10: More glucose tissue, [1].

here μa is the absorption coefficient and l are the effective optical path length μa is proportional to εC

“cm−1, where ε represents the molar extinction coefficient and C is the molar concentration of the

analyte”. “μa may increase with an elevated glucose level due to its intrinsic absorption or decrease due

to a water displacement effect”.

# CHAPTER 3

# DESIGN AND IMPLEMENTATION

## 1.13 Background of experiment

To measure blood sugar in a non-invasive way, as we mentioned earlier, the NIR rays

penetrate the skin and the rays interact with the finger tissues and glucose concentration and

then are reflected, and this reflected light is an electric current and then it is converted into

an electric potential. We were looking for a lot of sensors that read the output voltage. Then

we compared the results of the effort with the concentration of blood sugar by the gaseous

method and extracted the relationship and then finished the design of the device

## 1.14Initial work

We have tried to make a sensor, circuit that contains an IR transmitter and an IR photodiode

receiver, the designed circuit consists of filtering stage and amplification stage.

We finished making the circuit and used an oscilloscope to compare the input with the output

and we noticed that there were problems, so we decided to look for another sensor.

## 1.15 Parts aspect

We choose to use these components and conclude our circuit design upon reading lots of

scientific papers and articles that were using different kind of parts, the suitable parts for our

project that fulfil the accuracy and low-cost terms, these components are:

i. Arduino

ii. IR transmitter and receiver

iii. LCD

iv. Bluetooth

v. breadboard, power supply, resistors, wires

Figure 13 Output for first sensor

Figure 12 Simulation for first circuit. Figure 11 Circuit for first sensor.

## Parts explanation:

1.15.1Arduino UNO

“Arduino Uno is a microcontroller board based on the ATmega328P (datasheet). It has 14

digital input/output pins (of which 6 can be used as PWM outputs), 6 analog inputs, a 16 MHz

quartz crystal, a USB connection, a power jack, an ICSP header and a reset button”. We will

connect all the parts with the Arduino which it makes the Arduino the main controller of the

whole device.

1.15.2 IR transmitter and receiver

We used a sensor that contains the above components which they’re 5mm 940nm IR Emitter

Transmitter LED Diode Lights, Clear Infrared DC 1.2V with 30mA and 100mW, for the receiver

it’s a 5mm Photodiode with 840nm to 1100nm spectral density and has 940nm as a peak

wavelength, after that the sensor contain an amplifier and current to voltage converter which

will convert the conducting current from the transmitter and receiver to voltage, then amplify

this voltage.

Figure 14 Arduino component

Figure 16: IR transmitter with 940nm wavelength [23] Figure 15: IR photodiode receiver with spectral range of 840nm-1100nm and a peak wavelength 940nm [24]

1.15.3LCD

An electronic device that is used to display data and the message is known as LCD 16×2. As

the name suggests, it includes 16 Columns & 2 Rows so it can display 32 characters (16×2=32)

in total & every character will be made with 5×8 (40) Pixel Dots. This part will be used in this

project to display the amount of glucose in the blood and state a comment if its [Low-

Medium- High].

1.15.4Bluetooth [HC-06]

The HC-06 is a class 2 slave Bluetooth module designed for transparent wireless serial

communication. Once it is paired to a master Bluetooth device such as PC, smart phones and

tablet, its operation becomes transparent to the user. All data received through the serial

input is immediately transmitted over the air. This module will be used at this project to

connect the smart phone to this prototype, which the devise will send a message through the

app that’s made specially for this project, the message will include the state of glucose if its

Low, Medium, or High.

Figure 17: LCD component.

Figure 18: HC_06 Bluetooth module, [25]

## 1.16Block diagram of proposed work

The proposed work is based on NIR optical technique. NIR light source of 940 nm wavelength

is chosen because it is suitable for measuring blood glucose concentration. The sensing unit

consists of NIR emitter and NIR receiver (photodetector) positioned on either side of the

measurement site (fingertip). When the NIR light is propagated through the fingertip in which

it interacts with the glucose molecule, a part of NIR light gets absorbed depending on the

glucose concentration of blood and remaining part is passed through the fingertip. The

amount of NIR light passing through the fingertip depends on the amount of blood glucose

concentration.

Figure 19:Block diagram of noninvasive glucose concentration measurement system, [9].

The transmitted signal is detected by the photodetector. The output current of the photo

detector is converted into voltage signal and then it is filtered and amplified in the sensor.

This amplified signal is fed into the Arduino. This signal is processed by using second order

regression analysis to predict the blood glucose value and the blood glucose value is displayed

on the LCD display. A mobile application (App) is created to view and store the predicted

blood glucose value after receiving it via Bluetooth. Atmel communicates to the mobile app

via Bluetooth by connecting a Bluetooth module (HC-06) to it. The flow chart of proposed

work is shown in the following diagram The circuit diagram of the designed system consists of

sensor that do filtering stage and amplification stage. The electrical current obtained from the

photo detector is converted into voltage.

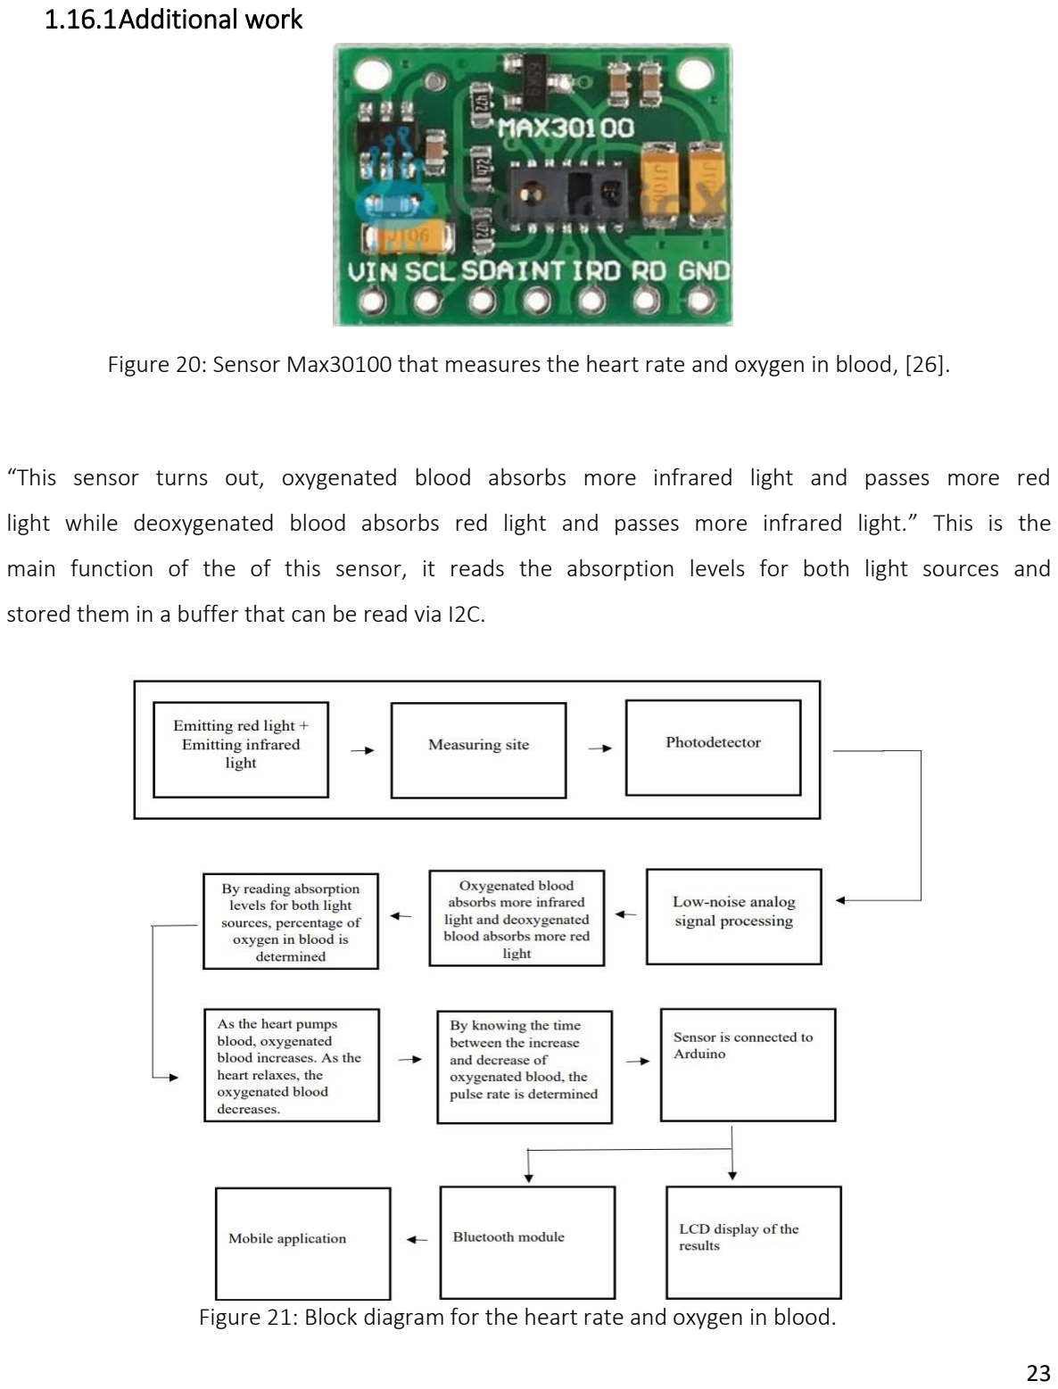
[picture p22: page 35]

1.16.1Additional work

Figure 20: Sensor Max30100 that measures the heart rate and oxygen in blood, [26].

“This sensor turns out, oxygenated blood absorbs more infrared light and passes more red

light while deoxygenated blood absorbs red light and passes more infrared light.” This is the

main function of the of this sensor, it reads the absorption levels for both light sources and

stored them in a buffer that can be read via I2C.

Figure 21: Block diagram for the heart rate and oxygen in blood.

## 1.17 Beginning of work

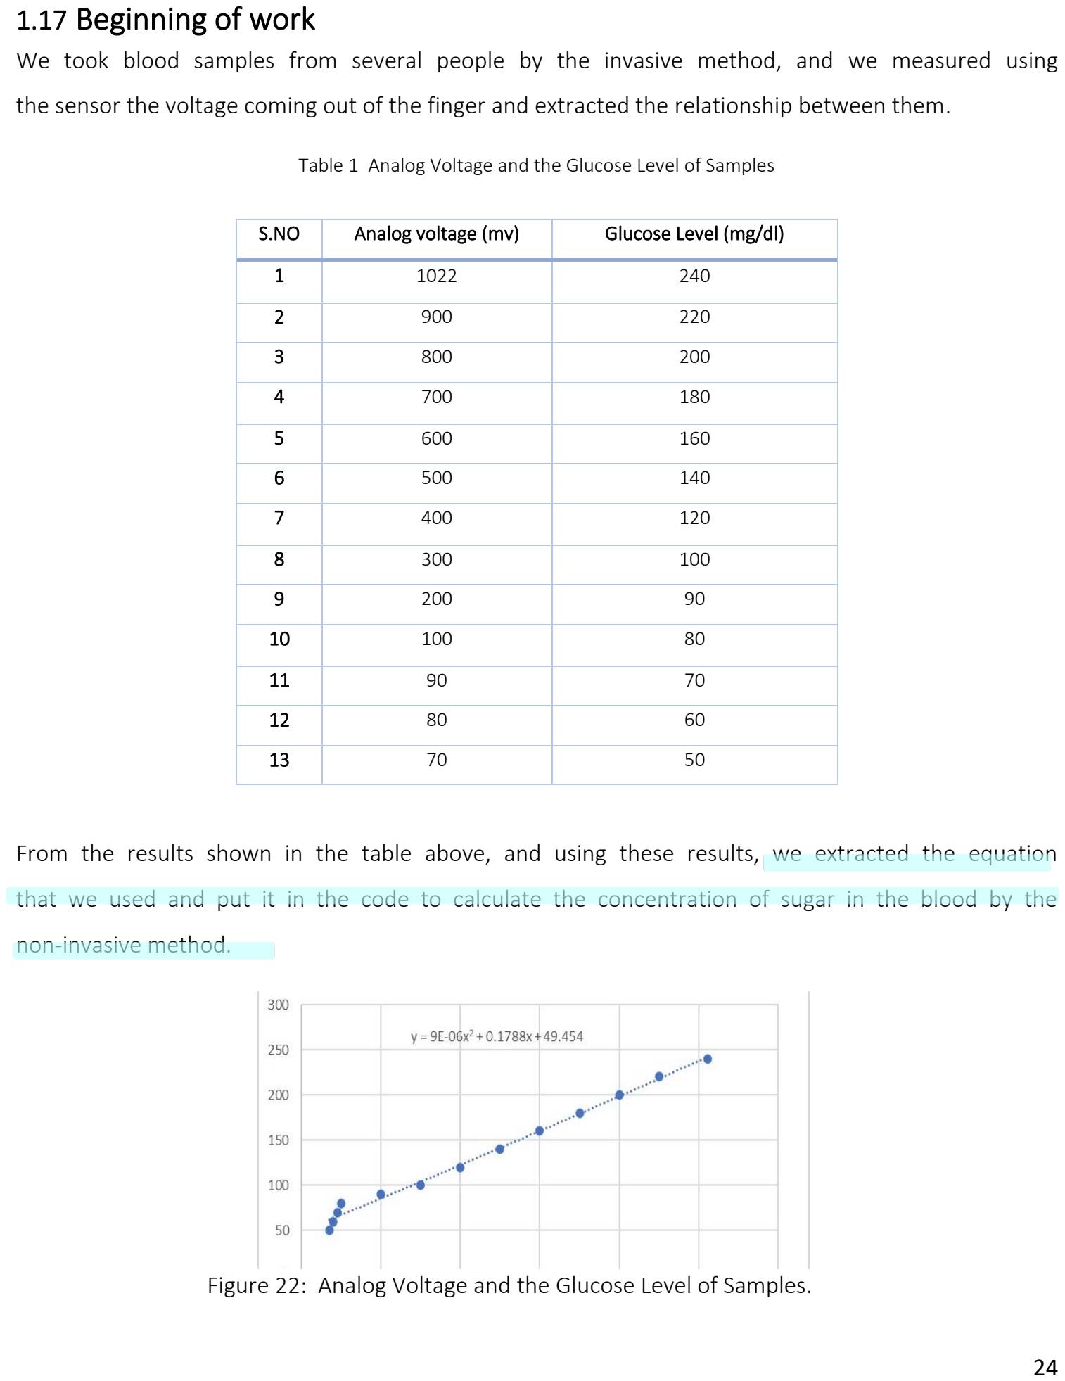
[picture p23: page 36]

We took blood samples from several people by the invasive method, and we measured using

the sensor the voltage coming out of the finger and extracted the relationship between them.

Table 1 Analog Voltage and the Glucose Level of Samples

From the results shown in the table above, and using these results, we extracted the equation

that we used and put it in the code to calculate the concentration of sugar in the blood by the

non-invasive method.

S.NO | Analog voltage (mv) | Glucose Level (mg/dl)
1 | 1022 | 240
2 | 900 | 220
3 | 800 | 200
4 | 700 | 180
5 | 600 | 160
6 | 500 | 140
7 | 400 | 120
8 | 300 | 100
9 | 200 | 90
10 | 100 | 80
11 | 90 | 70
12 | 80 | 60
13 | 70 | 50

Figure 22: Analog Voltage and the Glucose Level of Samples.

## 1.18 Flowcharts

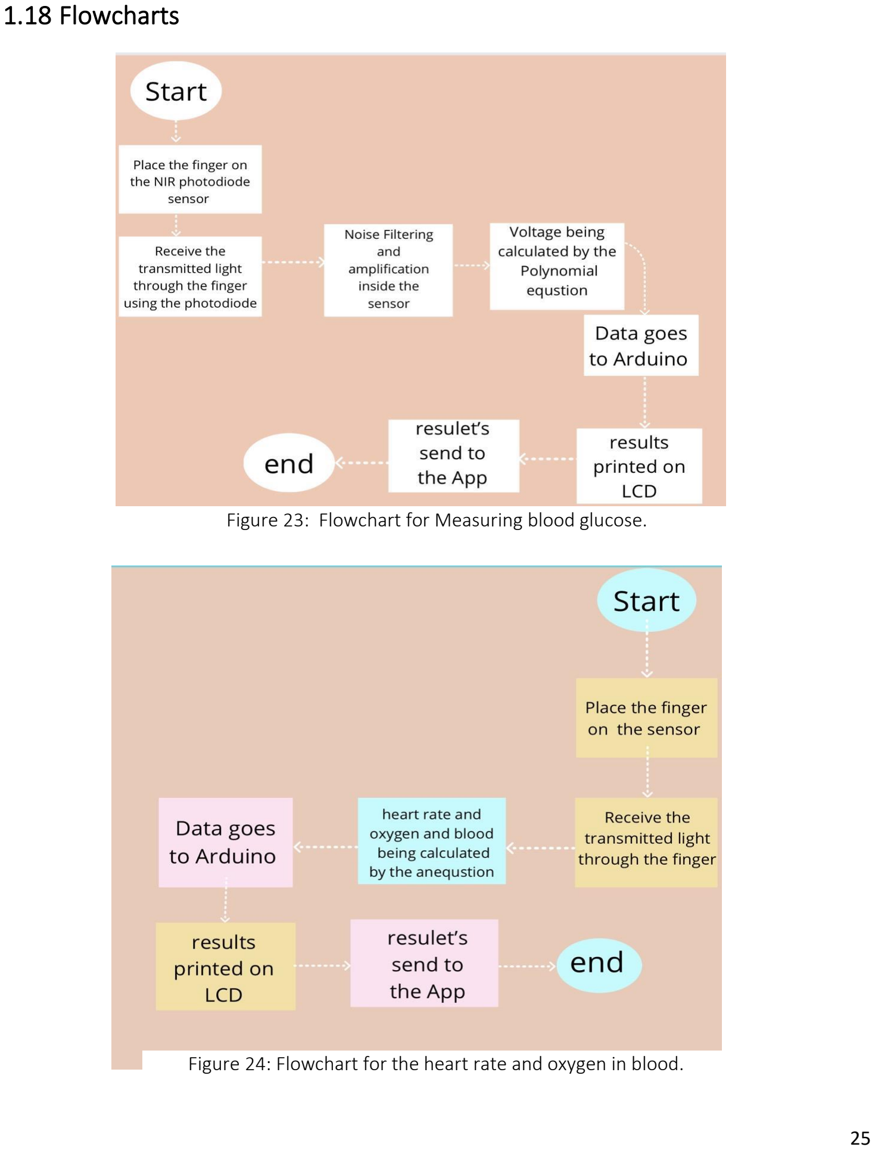
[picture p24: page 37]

Figure 23: Flowchart for Measuring blood glucose.

Figure 24: Flowchart for the heart rate and oxygen in blood.

## 1.19 Coding aspect:


We will need a C++ code (which will be installed in the Arduino microcontroller using the

Arduino software) for the following reasons:

a) To input an equation that will be used regularly.
b) We will need code for the output voltage of the photodiode for the Arduino to

recognize it as an input and process the data.

c) A code for the LCD screen for the Arduino to recognize it as an output & display result.

Figure 25: The heart rate and oxygen in blood code.

Figure 26: “Blood glucose code”.

1.19.1 Code explanation:
THE GLUCOSE CODE EXPLANATION

First, we included the library that will be used to effectively connect and program the LCD, we

also identified the Arduino pins which will be connected to the LCD, and we chose an initial

float variable to represent the voltage level that will be processed and the result of processing

the input which will represent the glucose level. Second, we identified an analog pin as an

input that will be receiving the voltage, and we also informed the program that the LCD will

have the capacity to print 16 letters for two rows. Moreover, we used the command “analog

read” to read the analog data received which is the voltage level and we set that value to a

variable. After that, we substituted the voltage level in the equation which we found earlier

by analyzing the data to get the glucose level measurement. Finally, we used “if” command

for comparison to determine the if the glucose level is Low, High, or normal and print it on the

screen along with calculated result.

THE HEART RATE AND OXYGEN IN BLOOD CODE EXPLANATION

the necessary header files for MAX30100 and 16×2 LCD. As MAX30100 uses the I2C

communication | protocol | were | included. | In | void | setup(), | we | initialized | the | Serial

Communication with a baud rate of 115200, Then test condition for MAX30100 was written.

If it is successfully initialized, then we will see “SUCCESS” on the serial terminal; otherwise, it

will display “FAILED” wait for infinite time in for loop.Now, the current through the LED was

set. By default, the current through the LED is 50mA.the current set in this code through the

IR | LED | is | 7. | 6mA.The | pulse | is | detected | from | the | sensor | by | using | the

setOnBeatDetectedCallback function, which will call the onBeatdetected. In infinite void loop

(), function pox.update() updates the sensor reading. Finally, it will print the heart rate in bpm

and SpO2 in percentage on a LCD every second.


Figure 27: The fuzzy classification system.

Figure 28: A learning fuzzy classification system.


Figure 30: An implemented fuzzy classification system.

# CHAPTER 4

# RESULTS AND DIFFICULT


## The device

This is the final form of the device, to measure sugar without pain in a non-invasive way, you

must put your finger on the sensor firmly and firmly for 15 seconds, and we have added the

device to measure the percentage of oxygen in the blood and heart rate in the human body,

so you only have to put your finger on the other sensor, the Arduino will take over Calculate

them all and then the results will be displayed on the LCD screen.

Figure 32: The final look of the device.

Figure 31: How the device works.

## 1.20 Results from our device

These are the results we got out of our device and we compered them with those we extracted from the

invasive method and we found the difference between them.

Table 2 Difference between invasive and non-invasive

S.NO | Glucose value obtained by invasive method | Glucose value obtained by non-invasive method | Difference | S.NO | Glucose value obtained by invasive method | Glucose value obtained by non-invasive method | Difference
1 | 97 | 89 | -8 | 7 | 103 | 100 | -3
2 | 119 | 99 | -20 | 8 | 150 | 130 | -20
3 | 95 | 89 | +4 | 9 | 115 | 108 | -7
4 | 100 | 99 | -1 | 10 | 90 | 108 | +18
5 | 101 | 107 | +6 | 11 | 200 | 150 | -50
6 | 99 | 113 | +14 | 12 | 79 | 89 | +10

## 1.21 The methods

The accuracy of this proposed glucose measurement device is measured using two main

analysis methods: Clarke Error Grid Analysis and Surveillance Error grid analysis.

1.21.1 Clarke Error Grid Analysis
The Clarke Error Grid shows the differences between a blood glucose predictive

measurement and a reference measurement, it also shows the clinical significance of the

differences between these values. As observed, the x-axis corresponds to the reference value

and the y-axis corresponds to the prediction. The diagonal line shows the prediction value is

the same as the reference value. This grid is split into five main zones, Zone A is defined as

clinical accuracy while zones C, D, and E are considered clinical error, [10].

ZONE A: Clinically Accurate This zone holds the values that differ from the reference values no

more than 20 percent or the values in the hypoglycemic range (<70 mg/dl). According to the

literature, values in zone A are considered clinically accurate. These values would lead to

clinically correct treatment decisions.

ZONE B: Clinically Acceptable This zone holds values that differs more than 20 percent but

would lead to benign or no treatment based on assumptions.

ZONE C: Overcorrecting This zone leads to overcorrecting acceptable BG levels.

ZONE D: Failure to Detect This zone leads to failure to detect and treat errors in BG levels. The

actual BG levels are outside of the acceptable levels while the predictions lie within the

acceptable range.

ZONE E: Erroneous treatment This zone leads to erroneous treatment because prediction

values are opposite to actual BG levels, and treatment would be opposite to what is

recommended [10].

As observed, 95% of the values are in region {A} which is considered medically acceptable

region for measurement devices, [9].

Figure 33: Result of Clarke analysis, [9].

1.21.2 Surveillance Error grid analysis
The surveillance error grid (SEG) analysis is a tool for analysis and visualization of blood

glucose monitoring (BGM) errors, it is mainly used to determine the clinical accuracy and risk

range of continuous glucose monitoring device used in intensive care unit. For each data pair

of measured and reference glucose, the experts identified the degree of risk associated with

an action taken because of a measured BG reading, compared to the action that would have

been taken if the reference BG had been known. The degree of risk for hyperglycemia

identified by the experts was coded from 0 (none) to 4 (extreme) [11]


Figure 34: Result of Surveillance Analysis, [9].

The above is our results using the Surveillance Error grid analysis, we notice that the

visualization of color-coded accuracy makes it much easier and faster to conclude that the

proposed device is acceptable for glucose level monitoring as most of the glucose readings

are in dark green zone (no risk) and few glucose readings are in light green zone (slight risk).

## 1.22 Difficulties

At first, we had a lot of difficulties in how we can design our own circuit, then things started

to be clear, the hardest part was ordering some of the components because they weren’t

available in Bahrain electrical and electronic markets, after the components arrived, we found

the coding a little bit challenging, but we’ve been able to write the perfect coding with some

helping from a famous website like GitHub.

We tried to build a whole sensor by our own, but the process was too long and ruff because

of the amplification stage and error of the amplification when it multiplied with a high gain.

So, after digging more into the subject we found a sensor that’s similar to what we wanted to

build.

The big challenge was how to obtain the glucose equation by taking the samples from the

people, the hard part was stabilizing the sensor and remove everything that affects it so we

can take true and correct readings that’s without side effects.

# CHAPTER 5

# DISCUSSION

## 1.23 Discussion

After spending time researching, designing, and implementing our glucose level monitoring

device. We succeeded in making a device for measuring blood glucose in a non-invasive way

Based on the results presented in Table 2, we compared the results of our device with the

results of the invasive method of glucose meter and we calculated the differences between

the results, the differences between the two devices were very good, but the differences

were greater when we measured high blood sugar.

i. What’s new in this project?
The new thing in our project is that we were able to measure the heart beats and

oxygen in blood beside the blood glucose.

ii. | What’s new comparing to the other articles, how do you compare your results?
| Our project differs than the articles that we read with (simple hardware and
| application, easy to use and our results are almost in the same error percentage as
| ours).
iii. | What is the project constraining, standards, limits, specifications?
| Limitations: are things that effect the sensor reading which make it not efficient and
| get higher error% they are (light, person skin thin or thick, persons weight)
| constrains: The sensor has some constrains which make it in can’t read in specific
| voltage which mean high percentage error in some points.
iv. | specifications: easy hardware, parts are available everywhere, low percentage
| error.

## 1.24 Total cost of the project

Table 3 Total cost

Device | Amount | Cost (BD)
Arduino uno | 1 | 2.500
sensors | 2 | 0 from uni
wires | 2 set of wires | 0.700
Bluetooth HC-06 | 1 | 2.500
Breadboard | 1 | 0.800
LCD | 1 | 2.000

Total cost = 8.500 BD

# CHAPTER 5

# CONCLUSION AND FUTURE WORK

To accomplish this project, we read many articles and journals to attempt to design and

implement a non-invasive Method for Glucose level monitoring. This method mainly Relies on

the NIR light. as we send the wavelength into that finger and measure the reflected amount

of the NIR which differs based on the amount of Glucose In the blood. We took samples using

the traditional invasive way and our device and found the correlation between both results

Using a mathematical equation. This equation is inserted into the Arduino’s microcontroller

and continuously used to find the glucose level in a non-invasive way. To make sure that our

results are accurate and acceptable we used two analyses to find the error percentage and it

didn’t exceed 20% which makes our device clinically acceptable for usage. This project helped

us on how to design, implement and how to bring life to what was once only an idea in our

head. we learned a lot of lessons that benefited us as students and will continue to be

valuable Information for us as engineers in the near future. As engineers, we are problems-

solvers, and we hope to bring to the medical world more designs and solutions that help

those who are in need.

# REFERENCES

[1] “NIR Based Non-Invasive Blood Glucose Measurement” Indian Journal of Science and Technology,

Vol 9(41), DOI: 10.17485/ijst/2016/v9i41/98996, November 2016 [Accessed: 17-Feb-2022]

[2] “The History of Diabetes” https://www.everydayhealth.com/diabetes/understanding/diabetes-

mellitus-through-time.aspx (https://www.everydayhealth.com/diabetes/understanding/diabetes-mellitus-through-time.aspx) [Accessed: 12-Feb-2022]

[3] “Picture of the Skin” https://www.webmd.com/skin-problems-and-treatments/picture-of-the-skin
[4] “Diabetes” https://en.wikipedia.org/wiki/Diabetes [Accessed: 22-Feb-2022]
[5] “What should my blood glucose level be?”

https://www.medicalnewstoday.com/articles/249413#what-is-a-healthy-blood-sugar-level [Accessed: 1-

March-2022]

[6] “What Is Glucose” https://www.webmd.com/diabetes/glucose-diabetes [Accessed:3-March-2022]
[7] “Non-Invasive Blood Glucose Monitoring Using Near Infrared Spectroscopy”

https://www.researchgate.net/publication/352244798_non_invasive_glucose_monitoring_2018

[Accessed: 2-Feb-2022]

[8] “Noninvasive Optical Diagnostic Techniques for Mobile Blood Glucose and Bilirubin Monitoring”

Bahareh Javid, Faranak Fotouhi- Ghazvini, Fahime Sadat Zakeri Department of Computer Engineering

and Information Technology, University of Qom, Qom, Iran [Accessed: 7-March-2022]

[9] “BLOOD GLUCOSE LEVEL MONITORING BY NONINVASIVE METHOD USING NEAR INFRA RED SENSOR”

International Journal of Latest Trends in Engineering and Technology pp. 141-147 DOI:

http://dx.doi.org/10.21172/1.IRES.19 e-ISSN:2278-621X [Accessed: 9-March-2022]

[10] “Clarke Error Grid” https://github.com/suetAndTie/ClarkeErrorGrid [Accessed: 9-April-2022]

[11] “Computing the Surveillance Error Grid Analysis: Procedure and Examples”

https://journals.sagepub.com/doi/full/10.1177/1932296814539590#:~:text=The%20surveillance%20err

or%20grid%20(SEG,rated%204%20distinct%20treatment%20scenarios. (https://journals.sagepub.com/doi/full/10.1177/1932296814539590) [Accessed: 9-April-2022]

[12] “Yadav J, Rani A, Singh V, Murari BM. Near‑infrared LED based non‑invasive blood glucose sensor.

2014 International Conference on Signal Processing and Integrated Networks (SPIN). Noida,

India: IEEE; 2014.”

[13] “Baharuddin H, Sulong MS, Joret A, Ab Rahman T, Ismail N. Bile pigments detection via IR sensor.

3rd Engineering Conference on Advancement in Mechanical and Manufacturing for Sustainable

Environment. Malaysia: 2010”

[14] Unnikrishna Menon KA, Hemachandran D,Abhishek TK. A survey on non-invasive blood glucose

monitoring using NIR., IEEE International Conference on Communications and Signal Processing (ICCSP).

2013 Apr;p. 1069-72.

[15] “Global and regional diabetes prevalence estimates for 2019 and projections for 2030 and 2045: Results from the International Diabetes Federation Diabetes Atlas, 9th edition”

https://www.diabetesresearchclinicalpractice.com/article/S0168-8227(19)31230-6/fulltext [Accessed:

12-Feb-2022]

[16] “Khalil OS. Non-invasive glucose measurement technologies: an update from 1999 to the dawn of

the new millennium. Diabetes Technology & Therapeutics. 2004 Oct; 6(5):660-97”

[17] “Chi-Fuk So, Kup-Sze Choi, Thomas KS Wong, Joanne WY Chung, “Recent advances in non invasive

glucose monitoring”, Medical Devices: Evidence and Research”

[18] " -Diabetes prevalence by age and sex in 2019" https://www.researchgate.net/figure/Diabetes-

prevalence-by-age-and-sex-in-2019_fig1_335732130 (https://www.researchgate.net/figure/Diabetes-prevalence-by-age-and-sex-in-2019_fig1_335732130) [Accessed: 11-Feb-2022]

[19]"a story of monstrous egos and toxic rivalries" https://theconversation.com/the-discovery-ofinsulin-a-story-of-monstrous-egos-and-toxic-rivalries-172820 (https://theconversation.com/the-discovery-of-insulin-a-story-of-monstrous-egos-and-toxic-rivalries-172820) [Accessed: 12-Feb-2022]

[20] " Diabetes Mellitus" https://www.homeogram.com/patient-care-and-health-information/diseases-

and-conditions/diabetes-mellitus/diabetes-mellitus/ (https://www.homeogram.com/patient-care-and-health-information/diseases-and-conditions/diabetes-mellitus/diabetes-mellitus/) [Accessed: 22-Feb-2022]


[21] " Understanding Type 1 Diabetes" https://fairviewmnhs.org/Patient-

Education/Articles/English/u/n/d/e/r/Understanding_Type_1_Diabetes_89523 (https://fairviewmnhs.org/Patient-Education/Articles/English/u/n/d/e/r/Understanding_Type_1_Diabetes_89523) [Accessed: 22-Feb-

2022]

[22] " ‘Noninvasive’ Glucose Monitoring for Diabetes: Where Is It Now?"

https://www.healthline.com/diabetesmine/non-invasive-diabetes-technology [Accessed: 12-Feb-2022]

[23] https://www.twinschip.com/Infrared_LED_5mm_94%20nm
[24] https://www.digikey.bg/en/products/detail/everlight-electronics-co-ltd/PD204-6B/2675630

[25]" Bluetooth Module HC-06" https://vaslabs.co.zw/product/bluetooth-module-hc-06/

[26] " MAX30100 Pluse Oximeter Heart Rate-Sensor"

https://www.indiamart.com/proddetail/max30100-pluse-oximeter-heart-rate-sensor-

22563404991.html

# APPENDIX

## Work schedule (Gantt Chart)


Table 4 Work schedule

Task Activity | Sep22-Jun17 | 18Jun-8Feb | 9Feb-2Mar | 3Mar-21Mar | 22Mar-15Apr | 16Apr-12May

## Reads articles

## Understanding the project

## Find the components and read about them

## Attempts to build the circuit

## Take samples to compete the design

## Completion of building the circuit & application

## Writing the report

View publication stats (https://www.researchgate.net/publication/360289594)

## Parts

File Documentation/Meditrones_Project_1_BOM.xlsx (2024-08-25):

 |  |  |  | BOM
Resistors
Item | Description | Designators | Package | Qty | Unit Price | Purchase Link | Datasheet link
1kR | 1k Ohm SMD Resistor | R2 | 0805 SMD | 1
680kR | 680k Ohm SMD Resistor | R3,R1 | 0805 SMD | 1 | 60 | https://tronic.lk/product/680k-18w-resistor-pack-smd-0805-1-approx-40pcs
68kR | 68k Ohm SMD Resistor | R4,R6 | 0805 SMD | 1 | 60 | https://tronic.lk/product/68k-18w-resistor-pack-smd-0805-1-approx-40pcs
6.8kR | 6.8k Ohm SMD Resistor | R5,R7 | 0805 SMD | 1 | 30 | https://www.duino.lk/product/6-3k-ohm-1-4w-smd-resistor-1206/
10kR | 10k Ohm SMD Resistor | R8 | 0805 SMD | 1 | 30 | https://tronic.lk/product/10k-18w-resistor-pack-smd-0805-1-approx-40pcs
330 R | 330 Ohm SMD Resistor | R1(PCB_2) | 0805 SMD | 1 | 60 | https://tronic.lk/product/330ohm-18w-resistor-pack-smd-0805-1-approx-40pcs
 |  |  |  |  | Total=240
Capacitors
Item | Description | Designators | Package | Qty | Unit Price | Purchase Link | Datasheet link
100nF | 100nF Ceramic Capacitor | C2,C4,C1,C6,C8,C9 | THT | 30 | 2 | https://tronic.lk/product/100nf-50v-ceramic-capacitor-tht
1uF | 1uF Ceramic Capacitor | C7,C3 | THT | 10 | 6.5 | https://nilambaraelectronics.com/product/ceramic-capacitors/
0.22uF | 220nF Ceramic Capacitor | C5 | THT | 10 | 6 | https://tronic.lk/product/224j-0-22uf-220nf-100v-mylar-capacitor-tht
22pF | 22pF Ceramic Capacitor | C10,C11 | THT | 10 | 3 | https://tronic.lk/product/22pf-ceramic-capacitor-tht
10uF | 10uF Electrolytic Capacitor | C12,C13 | THT | 10 | 4 | https://nilambaraelectronics.com/product/ceramic-capacitors/
 |  |  |  |  | Total=255
ICs
Item | Description | Designators | Package | Qty | Unit Price | Purchase Link | Datasheet link
Op-Amp | LM358N-Operational Amplifier | IC1 | THT | 3 | 30 | https://tronic.lk/product/lm358n-dual-differential-input-op-amp-operational-ampli
Atmega-328p-AU | micro-controller (SMD) | IC2 | SMD | 1 | 2360 | https://tronic.lk/product/atmel-atmega328p-au-microcontroller
Arduino Nano Board | To get the chip atmega 328p au |  |  | 1 | 1020 | Total=3470 | https://tronic.lk/product/arduino-nano-v3-0-original
Oscillators
Item | Description | Designators | Package | Qty | Unit Price | Purchase Link | Datasheet link
Oscillator | 16MHz Crystal Oscillator | Y1 | THT | 4 | 35 | https://tronic.lk/product/16mhz-crystal-oscillator
 |  |  |  |  | Total=140
Regulator
Item | Description | Designators | Package | Qty | Unit Price | Purchase Link | Datasheet link
5V Regulator | 5V voltage regulator | U1 | THT | 3 | 90 | https://tronic.lk/product/l7805cv-5v-voltage-regulator
 |  |  |  |  | Total=270
Switches
Item | Description | Designators | Package | Qty | Unit Price | Purchase Link | Datasheet link
Push Button | 4 Terminal push button | S1 | THT | 1 | 4
LEDs
Item | Description | Designators | Package | Qty | Unit Price | Purchase Link | Datasheet link
IR LED_1 | 940nm Through hole LED | D1 | THT | 10 | 10
IR LED_2 | 940nm SMD LED | LED1 | SMD 0805 | 20 pack | 200
 |  |  |  |  | Total=300
Connectors
Item | Description | Designators | Package | Qty | Unit Price | Purchase Link | Datasheet link
5 pin JST | 5 Way JST Headers-2.54mm | J1 | THT | 3 | 30 | https://tronic.lk/product/2-way-mini-jst-2-0-ph-connector-wire-microbit
4 pin JST | 4 Way JST Headers-2.54mm | J2,J5,J6 | THT | 6 | 25
2 pin JST | 2 Way JST Headers-2.54mm | J3,J4,J7,J1(PCB_02) | THT | 4 | 25
 |  |  |  |  | Total=340
OLED
Item | Description | Designators | Package | Qty | Unit Price | Purchase Link | Datasheet link
0.91inch 128x64 | OLED Display Module 128x64 |  | MODULE(Thru JST) | 2 | 650 | https://tronic.lk/product/0-96-inch-128x64-oled-display-module-blue-i2c-iic
 |  |  |  |  | Total=1300(One from Aazir)
 |  |  | Other Modules
Item | Description | Designators | Package | Qty | Unit Price | Purchase Link | Datasheet link
5V mini Booster | 5V step up booster |  | MODULE(Thru JST) | 1 | 360 | https://tronic.lk/product/multi-function-mini-boost-module-step-up-board-58912v-1
IR Receiver Module | CJMCU 101 opto |  | MODULE(Thru JST) | 2 | 2800 | https://tronic.lk/product/cjmcu-101-opt101-light-intensity-sensor-module
Battery Case | 2 Way AAA Battery case |  | Casing | 1 | 45
 |  |  |  |  | Total=6005
Soldering Material
Item | Description | Designators | Package | Qty | Unit Price | Purchase Link | Datasheet link
Solder Paste | Soldering Lead(40g) |  |  | 1 | 520
Flux Paste | Flux Paste for soldering |  |  | 1 | 150
Soldering Material | Microcontroller soldering expense |  |  |  | 800
 |  |  |  |  | Total=1470
 |  | Expenses from initial test circuit = 3200 (800 due from sahan, others paid)
 |  |  | Enclosure design costs |  | 3800(paid by aazir)
 |  |  | Other stationary |  | 200(paid by aazir)
 |  |  | PCB Costs |  | 11585 | >paid to pahasara
 |  |  | Component and Other |  | 13790
 |  |  | Total so Far: |  | 29375
 |  |  | Expenses for Manuri | 662 |  | 165 per person
 |  |  | Expenses for aazir | 3800+200+650 |  | 1160 per person
 |  |  | Expenses for Banuka=13,440 | 12778 |  | 3190 per person
 |  |  | PCB expenses are paid
 |  |  | Total overdue amount =17,790
 | Total Amount due to Aazir=3480
 | Total Amount due to Banuka=9,570+ initial 800 from sahan
 | Total Amount due to Manuri=495
 | Amounts owe by each person
 | Aazir to Banuka=3190-1160=2030
 | Sahan to Banuka=3190+800=3990
 | Sahan to Aazir= 1160
 | Sahan to Manuri=165
 | Manuri to Banuka=3190-165=3025
 | Manuri to Aazir=1160

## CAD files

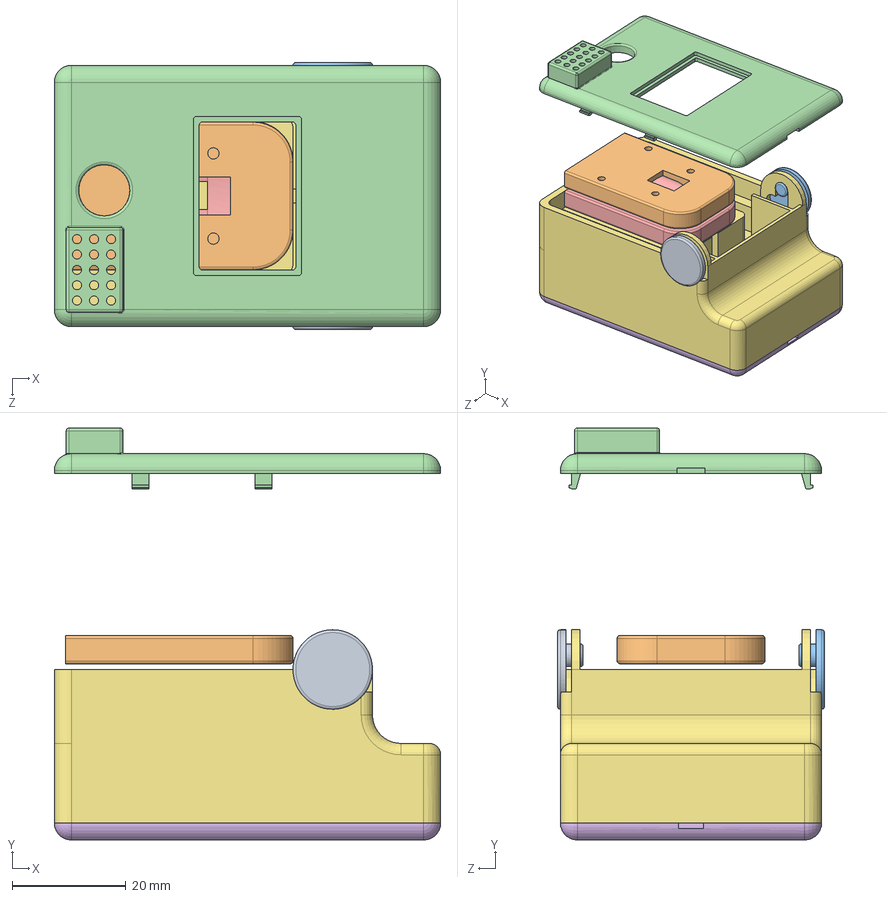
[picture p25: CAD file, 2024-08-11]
Enclosure/final-assembly.SLDASM
68.0 x 72.5 x 47.0 mm
bottomcompartmentlast
bottomlid
padding-final
Lid
side knob
rubberpadding-top
side knob2

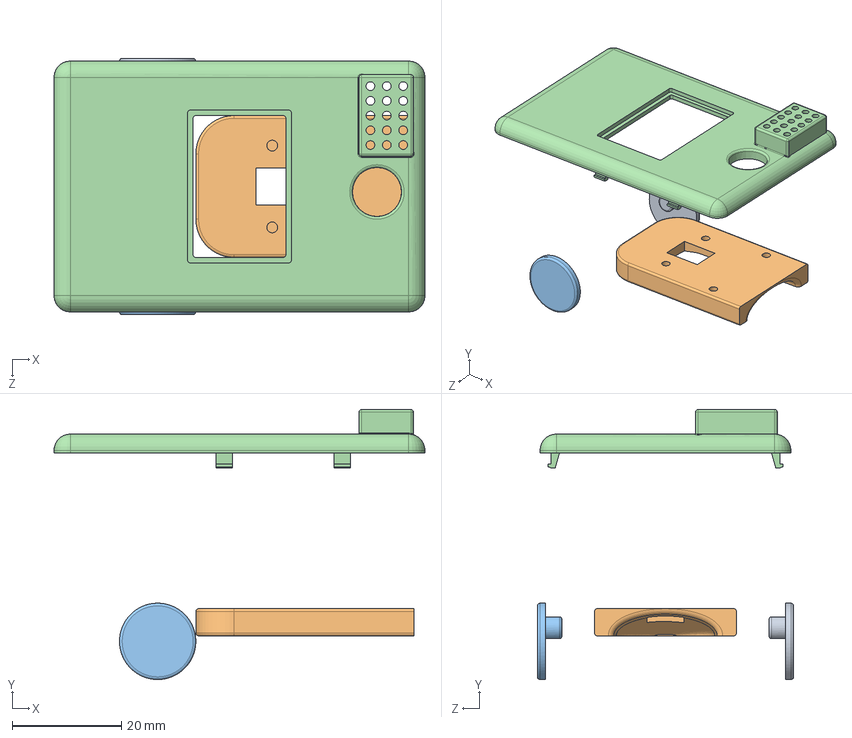
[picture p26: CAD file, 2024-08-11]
Enclosure/Combined.SLDASM
68.0 x 49.5 x 47.0 mm
Lid
side knob
rubberpadding-top
side knob2

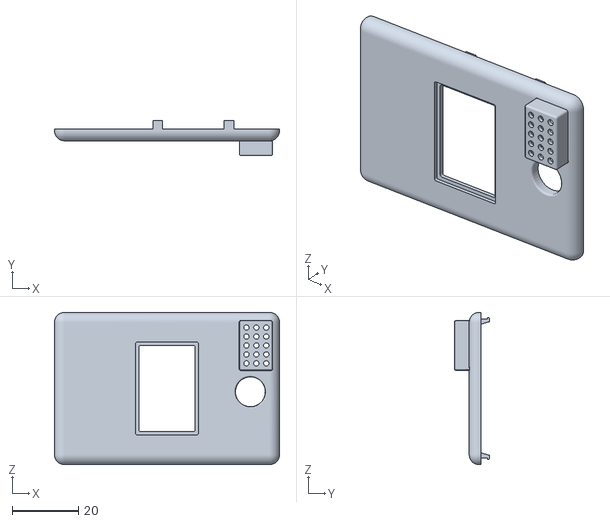
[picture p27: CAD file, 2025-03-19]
Enclosure/3D View/TopLid.STL
68.0 x 10.7 x 46.0

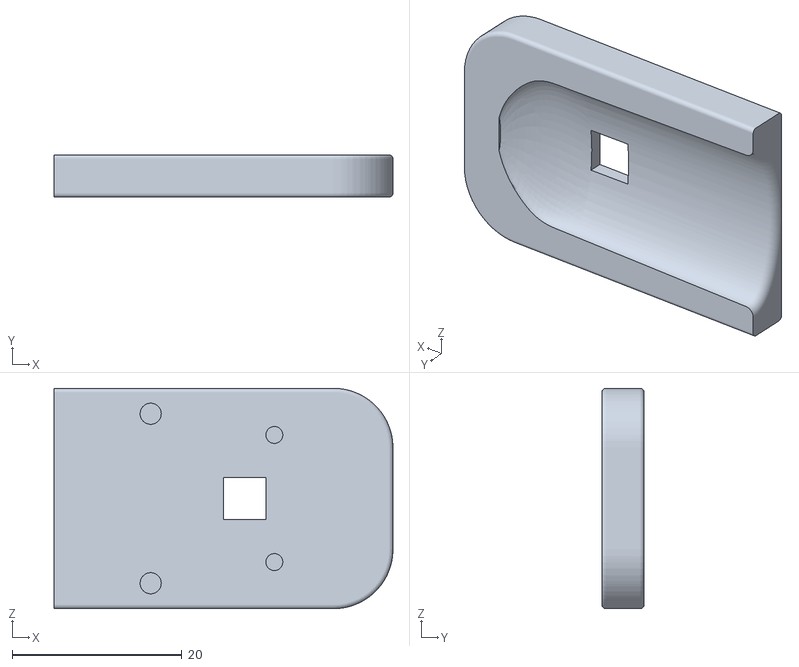
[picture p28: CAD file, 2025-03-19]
Enclosure/3D View/padding-bottom.STL
40.0 x 5.00 x 26.0

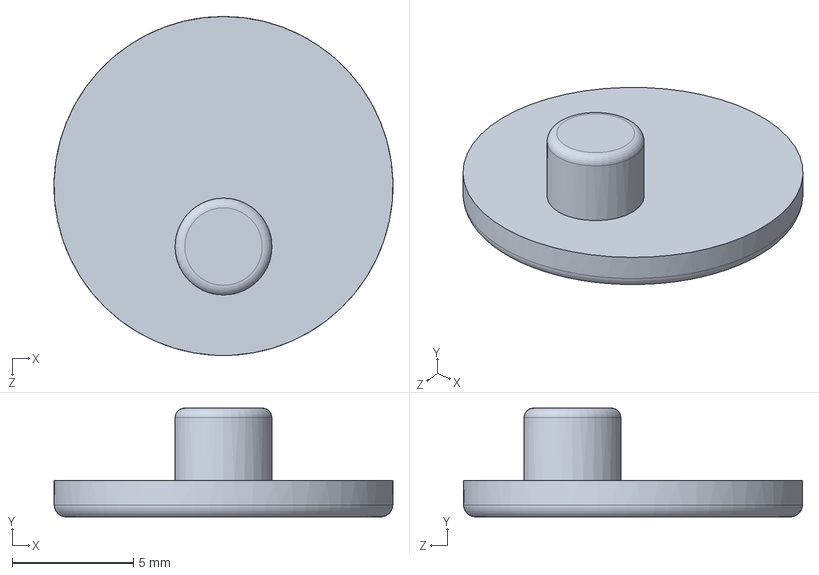
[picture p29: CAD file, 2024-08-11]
Enclosure/side knob.SLDPRT
14.0 x 4.50 x 14.0 mm

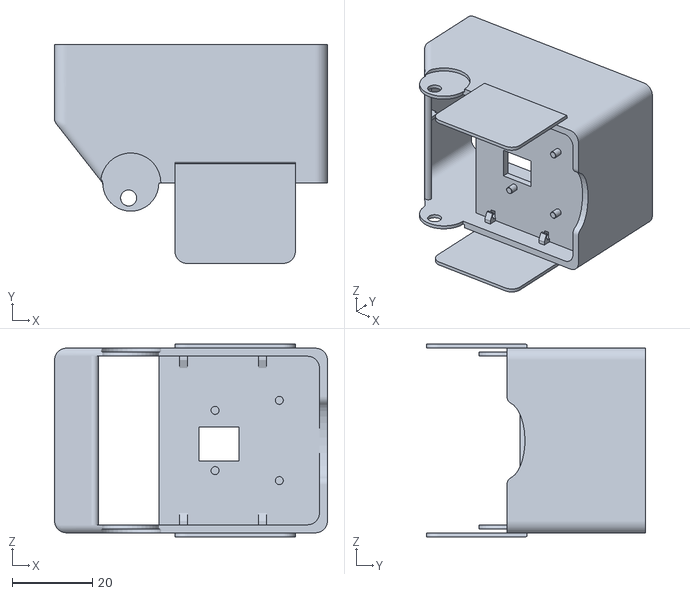
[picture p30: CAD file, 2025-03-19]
Enclosure/3D View/TopCompartment.STL
68.0 x 54.5 x 48.0

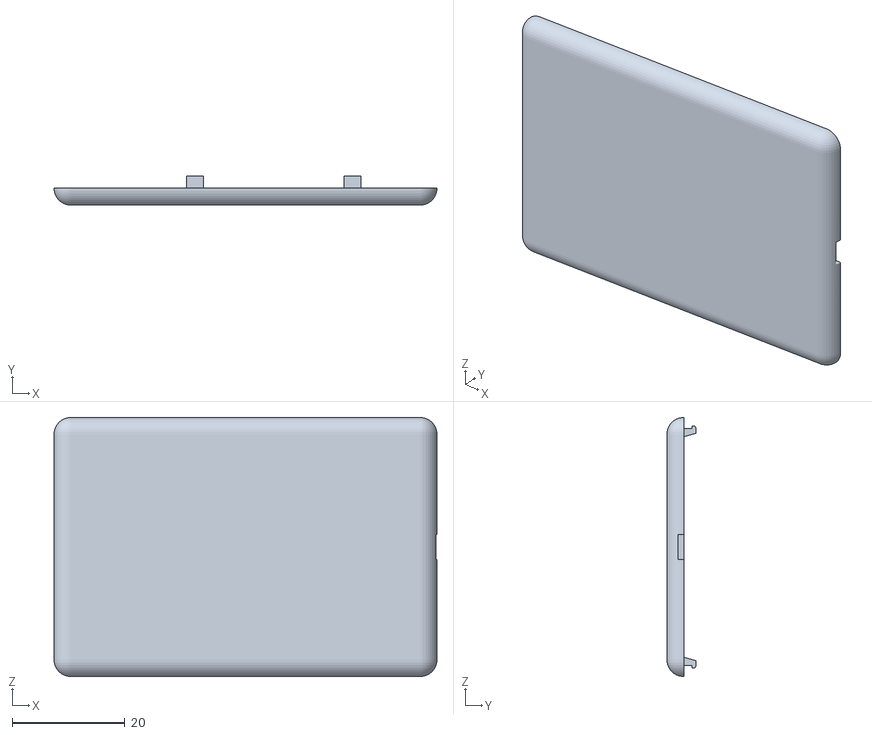
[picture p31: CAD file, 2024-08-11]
Enclosure/3D View/BottomLid.STL
68.0 x 5.20 x 46.0

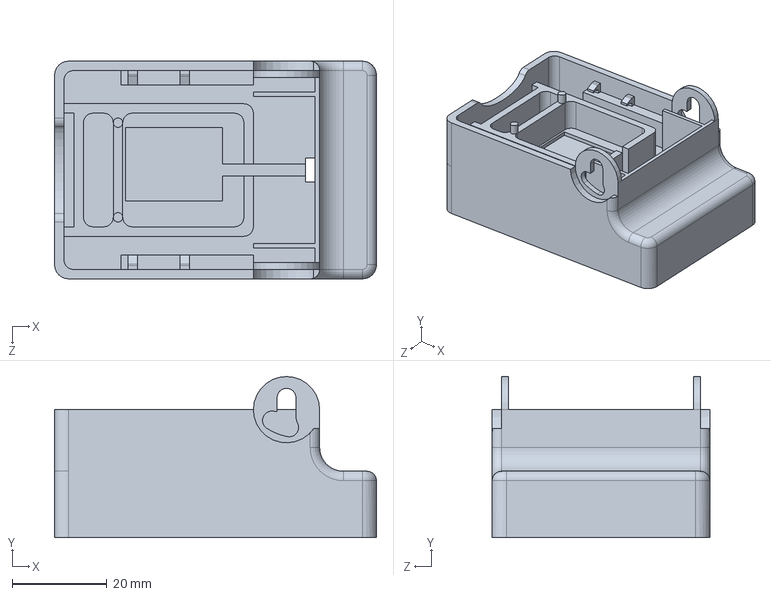
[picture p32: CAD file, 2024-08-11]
Enclosure/bottomcompartmentlast.SLDPRT
68.0 x 34.0 x 46.0 mm

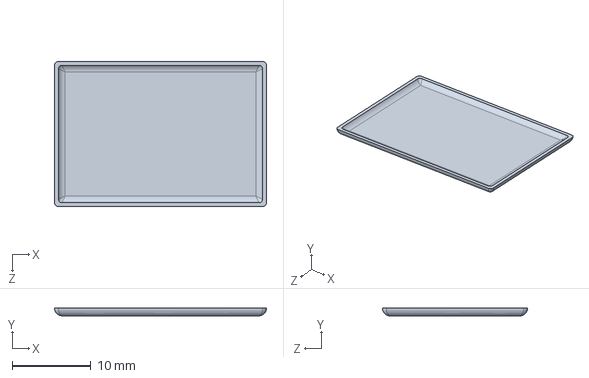
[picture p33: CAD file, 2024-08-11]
Enclosure/oled protector.SLDPRT
27.0 x 1.00 x 18.5 mm

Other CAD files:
Enclosure/3D View/rubberpadding-top.STL
Enclosure/padding-final.SLDPRT
Enclosure/3D View/BottomCompartment.STL
Enclosure/rubberpadding-top.SLDPRT
Enclosure/bottomlid.SLDPRT
Enclosure/side knob2.SLDPRT
Enclosure/Lid.SLDPRT

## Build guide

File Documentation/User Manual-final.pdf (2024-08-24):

APRICK by Meditrones

### 1. Introduction

This device is designed to provide a non-invasive way to measure your blood glucose level. It is suitable for use at home.

### 2. Safety Information

- Read the manual carefully before using the device.
- Only use the device as described in this manual.
- Keep out of reach of children.
- Do not use on neonates or infants.
- Do not attempt to repair or modify the device yourself.

### 3. Product Overview

Components:

- Fingertip Glucometer
- LiPo 3.7V 500mah battery
- User Manual

Features:

- Measures blood glucose level.
- OLED display for clear reading.
- Compact, portable, and lightweight design.
- Automatic power-off feature.

### 4. How to Use the Glucometer

- Insert the Batteries:
- Open the battery compartment on the back of the oximeter.
- Insert the Lithium Polymer battery to the compartment.
- Close the battery compartment.
- Turning On the Device:
- Press the power button to turn on the device.
- Using the Glucometer:
- Open the clamp and place your finger inside with the nail facing upwards.
- Ensure your finger is fully inserted, then release the clamp.
- Remain still while the device is measuring to get an accurate reading.
- The device will automatically start measuring your blood glucose level.
- Reading the Results:
- After 30 seconds, the results will display on the screen.
- Turning Off the Device:
- The glucometer will
automatically turn off after a few seconds of inactivity.
- Charging the battery:
- Remove the battery from the device and use battery charger to charge the battery.
- Do not overcharge the battery.

### 5. Maintenance and Care

- Clean the device with a soft, dry cloth.
- Avoid using harsh chemicals or solvents.
- Store the device in a cool, dry place.
- Remove the batteries if the device will not be used for an extended period.
- Do not submerge the device in water or any other liquid.

### 6. Troubleshooting

- No Display:
- Ensure the battery is correctly inserted.
- Recharge the battery if needed.
- Inaccurate Readings:
- Ensure your finger is correctly positioned.
- Stay still during the
measurement.
- Clean the sensor area.
- Device Not Turning Off:
- Wait for a few seconds, the device should turn off
automatically.

### 7. Technical Specifications

- Power Supply: 1xLiPo 3.7V 500mah battery
- Display: OLED display
- Dimensions: 6.8 x 4.5 x 6.2 cm

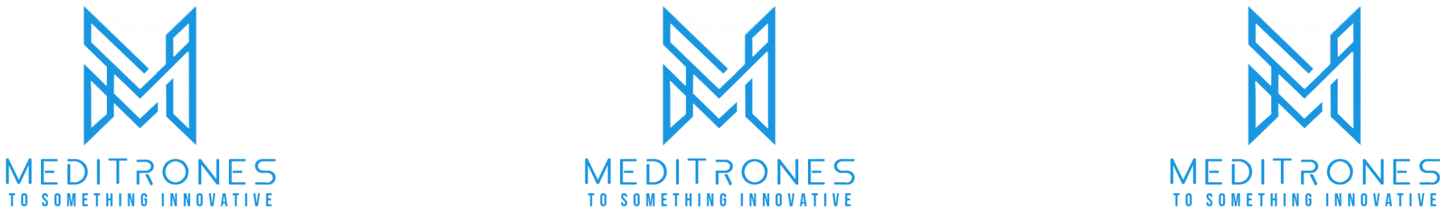
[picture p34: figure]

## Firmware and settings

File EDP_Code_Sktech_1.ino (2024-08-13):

#include <Wire.h>
#include <Adafruit_GFX.h>
#include <Adafruit_SSD1306.h>

// OLED display width and height, in pixels
#define SCREEN_WIDTH 128
#define SCREEN_HEIGHT 64

// Pin definitions
int sensorPin = A0; // Output from the receiver is connected to
const int receiverpin = 5; // Power up the receiver module
const int IR_LED_pin = 6; // Power up the IR LED
const int buttonPin = 2; // Pin connected to the button
const int ledPin = 13; // Pin connected to an LED (onboard LED for indication)
bool circuitState = false; // Variable to store the state of the circuit

// Declaration for an SSD1306 display connected to I2C (SDA, SCL pins)
Adafruit_SSD1306 display(SCREEN_WIDTH, SCREEN_HEIGHT, &Wire, -1);
// Image data
static const unsigned char PROGMEM image_data_Image_3[1024] = { 
    0xff, 0xff, 0xff, 0xff, 0xff, 0xff, 0xff, 0xff, 0xff, 0xff, 0xff, 0xff, 0xff, 0xff, 0xff, 0xff, 
    0xff, 0xff, 0xff, 0xff, 0xff, 0xff, 0xff, 0xff, 0xff, 0xff, 0xff, 0xff, 0xff, 0xff, 0xff, 0xff, 
    0xff, 0xff, 0xff, 0xff, 0xff, 0xff, 0xff, 0xff, 0xff, 0xff, 0xff, 0xff, 0xff, 0xff, 0xff, 0xff, 
    0xff, 0xff, 0xff, 0xff, 0xff, 0xff, 0xff, 0xff, 0xff, 0xff, 0xff, 0xff, 0xff, 0xff, 0xff, 0xff, 
    0xff, 0xff, 0xff, 0xff, 0xff, 0xff, 0xff, 0xff, 0xff, 0xff, 0xff, 0xff, 0xff, 0xff, 0xff, 0xff, 
    0xff, 0xff, 0xff, 0xff, 0xff, 0xff, 0xff, 0xff, 0xff, 0xff, 0xff, 0xff, 0xff, 0xff, 0xff, 0xff, 
    0xff, 0xff, 0xff, 0xff, 0xff, 0xff, 0xff, 0xff, 0xff, 0xff, 0xff, 0xff, 0xff, 0xff, 0xff, 0xff, 
    0xff, 0xff, 0xff, 0xff, 0xff, 0xff, 0xff, 0xff, 0xff, 0xff, 0xff, 0xff, 0xff, 0xff, 0xff, 0xff, 
    0xff, 0xff, 0xff, 0xff, 0xff, 0xff, 0xff, 0xff, 0xff, 0xff, 0xff, 0xff, 0xff, 0xff, 0xff, 0xff, 
    0xff, 0xff, 0xff, 0xff, 0xff, 0xff, 0xff, 0xff, 0xff, 0xff, 0xff, 0xff, 0xff, 0xff, 0xff, 0xff, 
    0xff, 0xff, 0xff, 0xff, 0xff, 0xff, 0xff, 0xff, 0xff, 0xff, 0xff, 0xff, 0xff, 0xff, 0xff, 0xff, 
    0xff, 0xff, 0xff, 0xff, 0xff, 0xff, 0xff, 0xff, 0xff, 0xff, 0xff, 0xff, 0xff, 0xff, 0xff, 0xff, 
    0xff, 0xff, 0xff, 0xff, 0xff, 0xff, 0xff, 0xff, 0xff, 0xff, 0xff, 0xff, 0xff, 0xff, 0xff, 0xff, 
    0xff, 0xff, 0xff, 0xff, 0xff, 0xff, 0xff, 0xff, 0xff, 0xff, 0xff, 0xff, 0xff, 0xff, 0xff, 0xff, 
    0xff, 0xff, 0xff, 0xff, 0xff, 0xff, 0xff, 0xff, 0xff, 0xff, 0xff, 0xff, 0xff, 0xff, 0xff, 0xff, 
    0xff, 0xff, 0xff, 0xff, 0xff, 0xff, 0xff, 0xff, 0xff, 0xff, 0xff, 0xff, 0xff, 0xff, 0xff, 0xff, 
    0xff, 0xff, 0xff, 0xff, 0xff, 0xff, 0xff, 0xff, 0xff, 0xff, 0xff, 0xff, 0xff, 0xff, 0xff, 0xff, 
    0xff, 0xff, 0xff, 0xff, 0xff, 0xff, 0xff, 0xff, 0xff, 0xef, 0xff, 0xff, 0xff, 0xff, 0xff, 0xff, 
    0xff, 0xff, 0xff, 0xff, 0xff, 0xff, 0xf9, 0xff, 0xff, 0x9f, 0xff, 0xff, 0xff, 0xff, 0xff, 0xff, 
    0xff, 0xff, 0xff, 0xff, 0xff, 0xff, 0xfe, 0x7f, 0xff, 0x6f, 0xff, 0xff, 0xff, 0xff, 0xff, 0xff, 
    0xff, 0xff, 0xff, 0xff, 0xff, 0xff, 0xff, 0xbf, 0xfc, 0xef, 0xff, 0xff, 0xff, 0xff, 0xff, 0xff, 
    0xff, 0xff, 0xff, 0xff, 0xff, 0xff, 0xfb, 0xcf, 0xfd, 0xff, 0xff, 0xff, 0xff, 0xff, 0xff, 0xff, 
    0xff, 0xff, 0xff, 0xff, 0xff, 0xff, 0xfd, 0xf7, 0xfd, 0x9f, 0xff, 0xff, 0xff, 0xff, 0xff, 0xff, 
    0xff, 0xff, 0xff, 0xff, 0xff, 0xff, 0xfe, 0xf9, 0xfd, 0x6f, 0xff, 0xff, 0xff, 0xff, 0xff, 0xff, 
    0xff, 0xff, 0xff, 0xff, 0xff, 0xff, 0xff, 0xbe, 0xfd, 0xef, 0xff, 0xff, 0xff, 0xff, 0xff, 0xff, 
    0xff, 0xff, 0xff, 0xff, 0xff, 0xff, 0xff, 0xdf, 0x73, 0xef, 0xff, 0xff, 0xff, 0xff, 0xff, 0xff, 
    0xff, 0xff, 0xff, 0xff, 0xff, 0xff, 0xf9, 0xb7, 0xef, 0xef, 0xff, 0xff, 0xff, 0xff, 0xff, 0xff, 
    0xff, 0xff, 0xff, 0xff, 0xff, 0xff, 0xfe, 0xb9, 0xdd, 0xef, 0xff, 0xff, 0xff, 0xff, 0xff, 0xff, 
    0xff, 0xff, 0xff, 0xff, 0xff, 0xff, 0xff, 0x3e, 0x7d, 0xef, 0xff, 0xff, 0xff, 0xff, 0xff, 0xff, 
    0xff, 0xff, 0xff, 0xff, 0xff, 0xff, 0xff, 0xdf, 0xfd, 0xef, 0xff, 0xff, 0xff, 0xff, 0xff, 0xff, 
    0xff, 0xff, 0xff, 0xff, 0xff, 0xff, 0xff, 0xb7, 0xfd, 0xef, 0xff, 0xff, 0xff, 0xff, 0xff, 0xff, 
    0xff, 0xff, 0xff, 0xff, 0xff, 0xff, 0xff, 0xbb, 0xdd, 0xef, 0xff, 0xff, 0xff, 0xff, 0xff, 0xff, 
    0xff, 0xff, 0xff, 0xff, 0xff, 0xff, 0xff, 0x7e, 0x3e, 0xef, 0xff, 0xff, 0xff, 0xff, 0xff, 0xff, 
    0xff, 0xff, 0xff, 0xff, 0xff, 0xff, 0xfe, 0xff, 0xff, 0x7f, 0xff, 0xff, 0xff, 0xff, 0xff, 0xff, 
    0xff, 0xff, 0xff, 0xff, 0xff, 0xff, 0xfb, 0xff, 0xff, 0xdf, 0xff, 0xff, 0xff, 0xff, 0xff, 0xff, 
    0xff, 0xff, 0xff, 0xff, 0xff, 0xff, 0xff, 0xff, 0xff, 0xff, 0xff, 0xff, 0xff, 0xff, 0xff, 0xff, 
    0xff, 0xff, 0xff, 0xff, 0xff, 0xff, 0xff, 0xff, 0xff, 0xff, 0xff, 0xff, 0xff, 0xff, 0xff, 0xff, 
    0xff, 0xff, 0xff, 0xff, 0xff, 0xff, 0xff, 0xff, 0xff, 0xff, 0xff, 0xff, 0xff, 0xff, 0xff, 0xff, 
    0xff, 0xff, 0xff, 0xff, 0xf7, 0x6f, 0xbf, 0xef, 0xdf, 0xf3, 0x7f, 0x7f, 0xff, 0xff, 0xff, 0xff, 
    0xff, 0xff, 0xff, 0xff, 0xf7, 0xef, 0xbf, 0xee, 0xbf, 0xf7, 0x6f, 0xff, 0xff, 0xff, 0xff, 0xff, 
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

void setup() {
  pinMode(receiverpin, OUTPUT); // Initialize receiver module pin
  digitalWrite(receiverpin, LOW); // Ensure receiver is off initially
  
  pinMode(IR_LED_pin, OUTPUT); // Initialize IR LED pin
  digitalWrite(IR_LED_pin, LOW); // Ensure IR LED is off initially
  
  pinMode(buttonPin, INPUT); // Initialize the button pin as an input

  pinMode(ledPin, OUTPUT); // Initialize the LED pin as an output
  digitalWrite(ledPin, LOW); // Turn off the LED initially

  Serial.begin(9600); // Initialize serial communication for debugging
  
  // Initialize the OLED display with I2C address 0x3C
  if (!display.begin(SSD1306_SWITCHCAPVCC, 0x3C)) {
    Serial.println(F("SSD1306 allocation failed"));
    for (;;); // Infinite loop to stop execution if display initialization fails
  } 
}

void loop() {
  // Read the state of the button
  int buttonState = digitalRead(buttonPin);

  // Check if the button is pressed
  if (buttonState == HIGH) {
      // Display startup image
    display.drawBitmap(0, 0, image_data_Image_3, 128, 64, 1);
    display.display();
    delay(2000);
    display.clearDisplay();
    // Display the welcome message
    display.clearDisplay();
    display.setTextSize(2);
    display.setTextColor(WHITE);
    display.setCursor(0, 10);
    display.println("APRICK by");
    display.println("MEDITRONES");
    display.display(); 
    delay(2000);
    display.clearDisplay();

    // Prompt user to place finger
    display.setTextSize(1);
    display.setTextColor(WHITE);
    display.setCursor(0, 10);
    display.println("Place the Finger");
    display.setCursor(0, 40);
    display.println("Wait for 30 seconds");
    display.display(); 

    // Power up the IR LED and receiver
    digitalWrite(IR_LED_pin, HIGH);
    digitalWrite(receiverpin, HIGH);

    // Start taking readings for 30 seconds
    const unsigned long duration = 30000; // 30 seconds in milliseconds
    const unsigned long interval = 500; // Interval between readings in milliseconds
    unsigned long startTime = millis();
    unsigned long currentTime;
    float totalVoltage = 0.0;
    int numReadings = 0;
    
    while ((currentTime = millis()) - startTime < duration) {
      int sensorValue = analogRead(sensorPin); // Read the analog value from the sensor
      float voltage = sensorValue * (5.0 / 1023.0); // Convert analog value to voltage (assuming 5V supply)
      totalVoltage += voltage;
      numReadings++;
      delay(interval);
    }

    // Calculate the average voltage
    float averageVoltage = totalVoltage / numReadings;
    Serial.print("Average Voltage over 30 seconds: ");
    Serial.println(averageVoltage);

    // Display the average voltage
    display.clearDisplay();
    display.setCursor(0, 10);
    display.setTextSize(1);
    display.println("Average Voltage:");
    display.setTextSize(2);
    display.setCursor(0, 30);
    display.print(averageVoltage);
    display.println(" Volts");
    display.display();
    delay(5000); // Display the result for 5 seconds

    // Shut down the device
    digitalWrite(IR_LED_pin, LOW); // Turn off the IR LED
    digitalWrite(receiverpin, LOW); // Turn off the receiver
    display.clearDisplay(); // Clear the display
    display.display(); // Ensure the display is updated
    delay(1000); // Small delay to ensure shutdown is complete
  }

  // Small debounce delay
  delay(50);
}

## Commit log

2024-08-25 Added BOM
    [Meditrones_Project_1.xlsx]
2025-03-03 remove wrong Dir
    [NIGM_EDP.PrjPcb, PCB1.PcbDoc, PcbLib1.PcbLib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]
2025-03-03 Add PCB File
    ✅ Added schematic files (.SchDoc)
    ✅ Added PCB layout (.PcbDoc)
    ✅ Included project libraries (.SchLib, .PcbLib)
    [NIGM_EDP.PrjPcb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]
